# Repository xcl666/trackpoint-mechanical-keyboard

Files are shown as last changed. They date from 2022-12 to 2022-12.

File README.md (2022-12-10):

1，qmk源码里面，keyboard里面xcl文件夹，对应相应的键盘

2，PCB源码，嘉立创

3，固件，在qmk_firmware下有相应的固件名称

4，欢迎进QQ群199606725交流学习

5, 发现这样写太累了，抽个时间，写个word，好好梳理一下吧，再传上来。

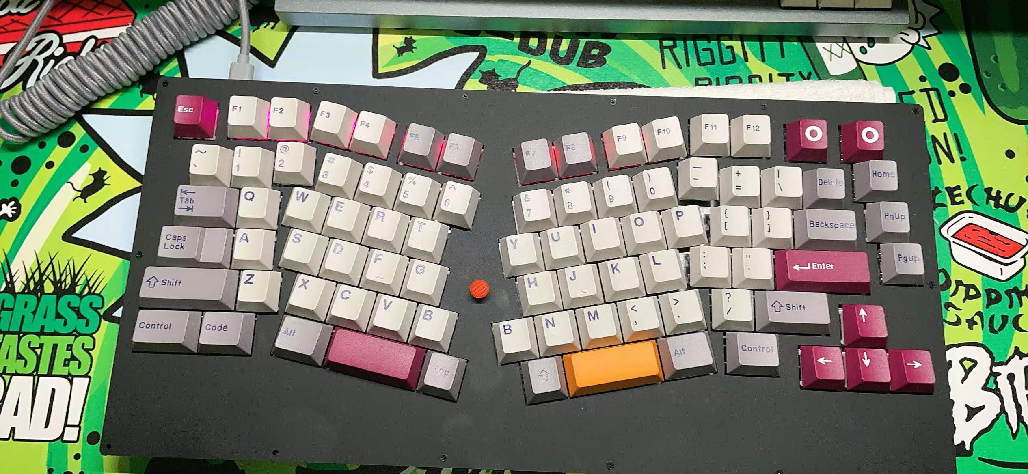
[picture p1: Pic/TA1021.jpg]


备注：qmk代码是参考 myst729

现在就开始讲一下怎么制作键盘了。

1， 先去嘉立创导入iceda里面的工程文件，打板子

2， 在嘉立创eda里面生产bom表，去淘宝或者嘉立创买各种元器件

3， 需要烙铁，风枪更好的，芯片多采用mu封装的，风枪还是必须的，如果手艺厉害，烙铁也可以，把各种元器件贴上去

4， 最好贴个最小系统，刷入qmk_firmware文件夹里面的hex估计，测试没问题，在焊二极管和轴座

5， 然后安装小红点模块，可以买8pin的0.5mm排线连接，顺序是V、G、C、L、M、R、R、D，中间三根不用焊，只要V G C R D这五根线

6， 需要用到PCB文件夹里面的外壳文件，亚克力切割外壳，定位板，定位板可以选择碳纤维、钢、亚克力等材质，规格是：

7， 外壳到了之后，需要2x12的铜柱，2x13的螺丝，2x6的螺丝

8，小红点支撑杆可以3D打印，有模型，不知道我传了没有。

9，装上轴和键帽，就走起了。

欢迎支持作者，让作者喝杯咖啡，继续完善DIY文档，哈哈，非常感谢

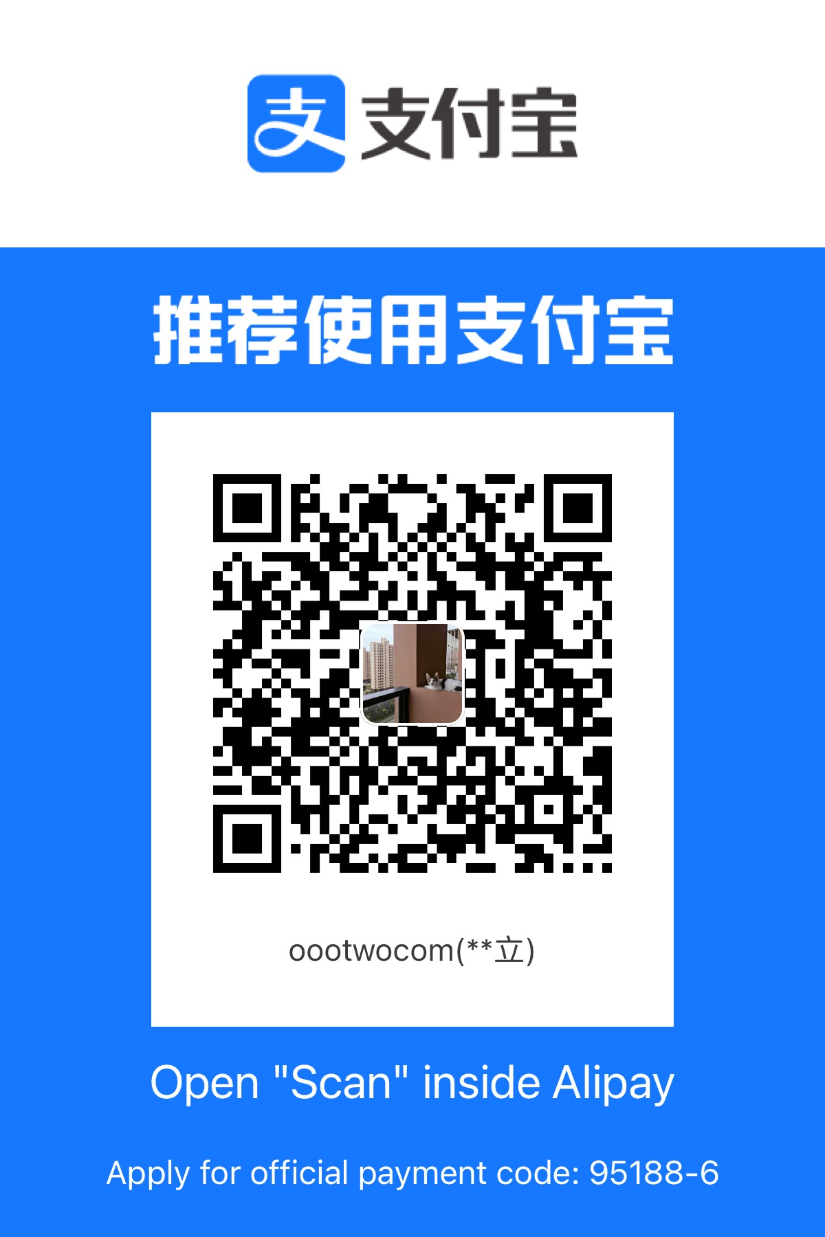
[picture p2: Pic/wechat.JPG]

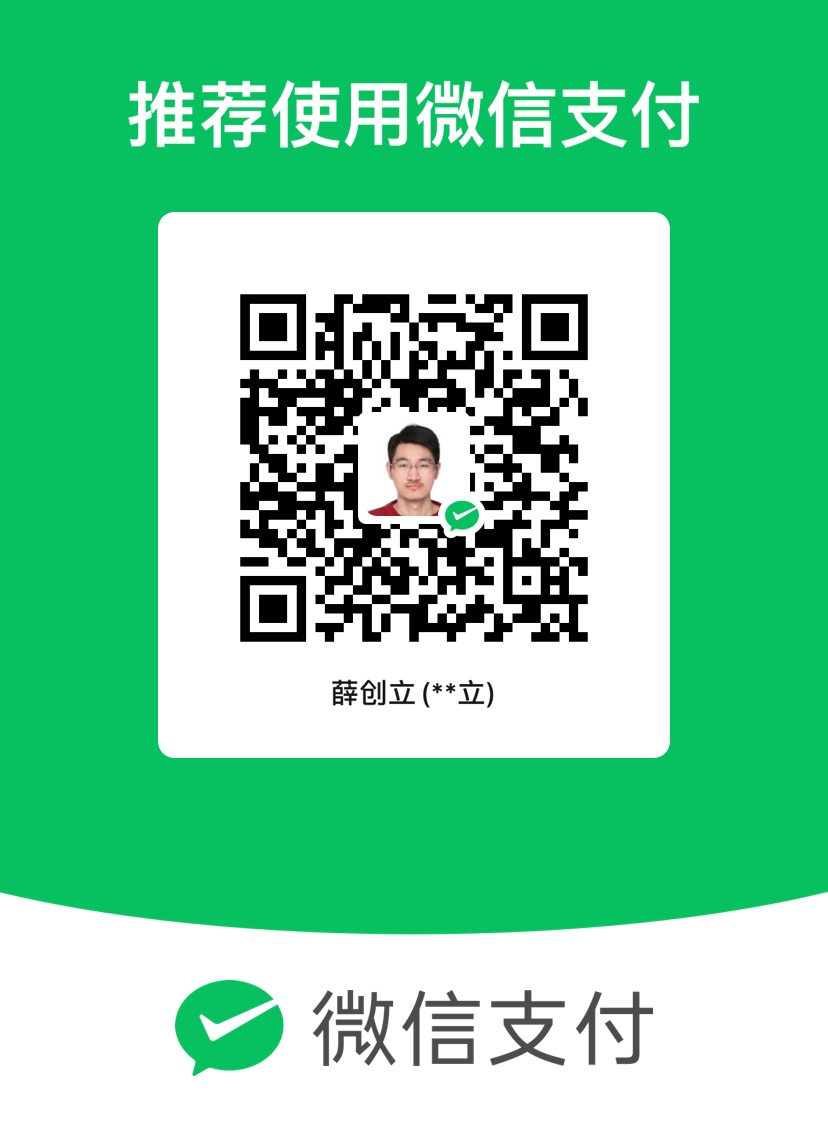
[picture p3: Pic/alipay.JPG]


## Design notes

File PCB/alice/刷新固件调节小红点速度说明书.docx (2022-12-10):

刷新固件调节小红点速度说明书

1. 在 群文件 qmk 里面下载安装qmk_toolbox.exe
2. 打开 qmk_toolbox.exe，勾选 autoflash，如下图

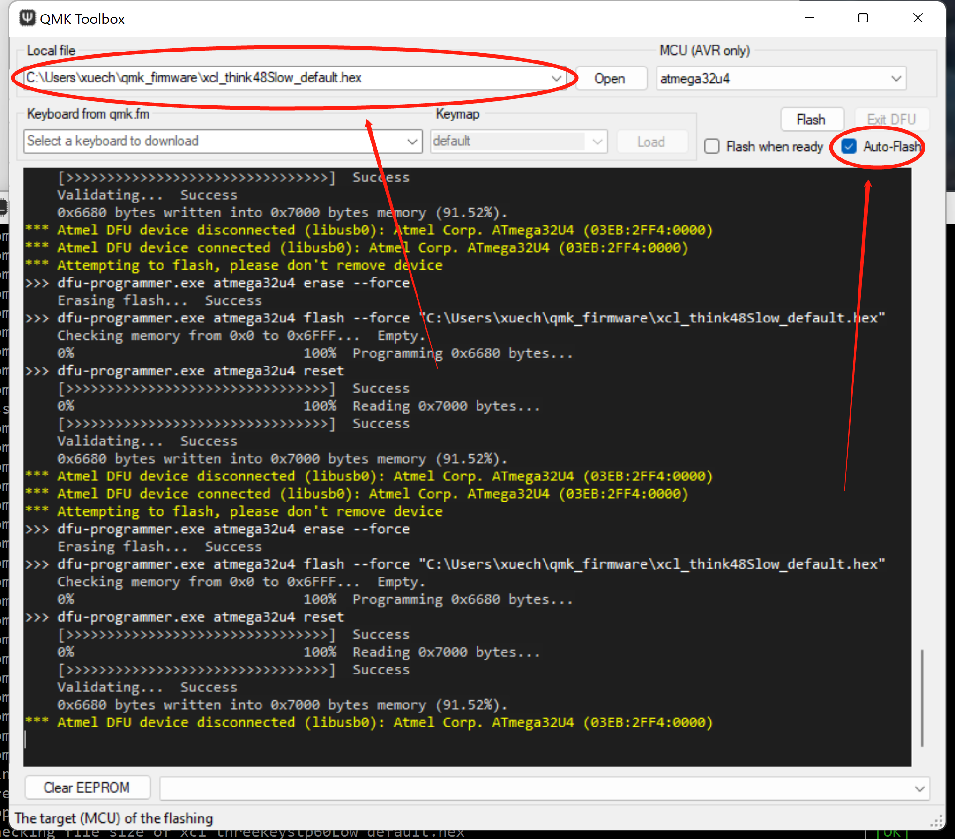
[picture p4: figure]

直接把 ***.hex 固件拖进图中方框里面

3，打开 via 软件

A. 按照下图箭头指向进行操作，保存当前键盘布局，以防出现刷固件之后出现按键回复刷机状态。

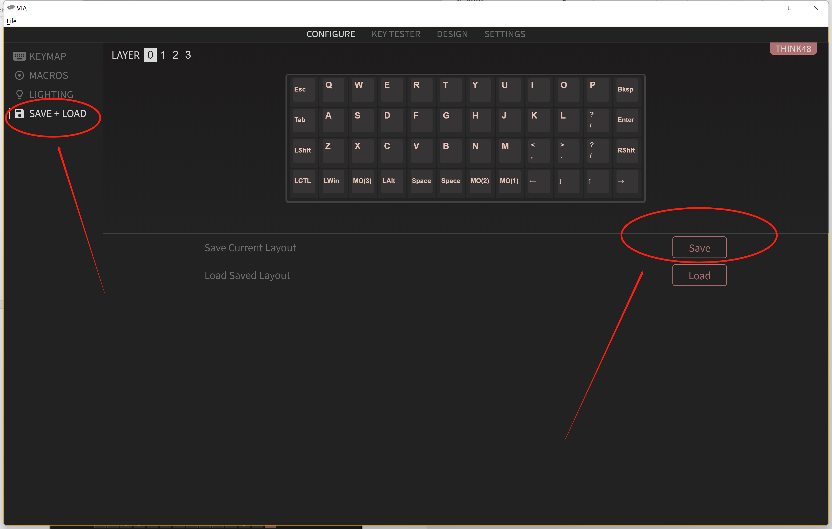
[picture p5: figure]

B. 按照下图操作，把 P 键设置为 Reset 按键

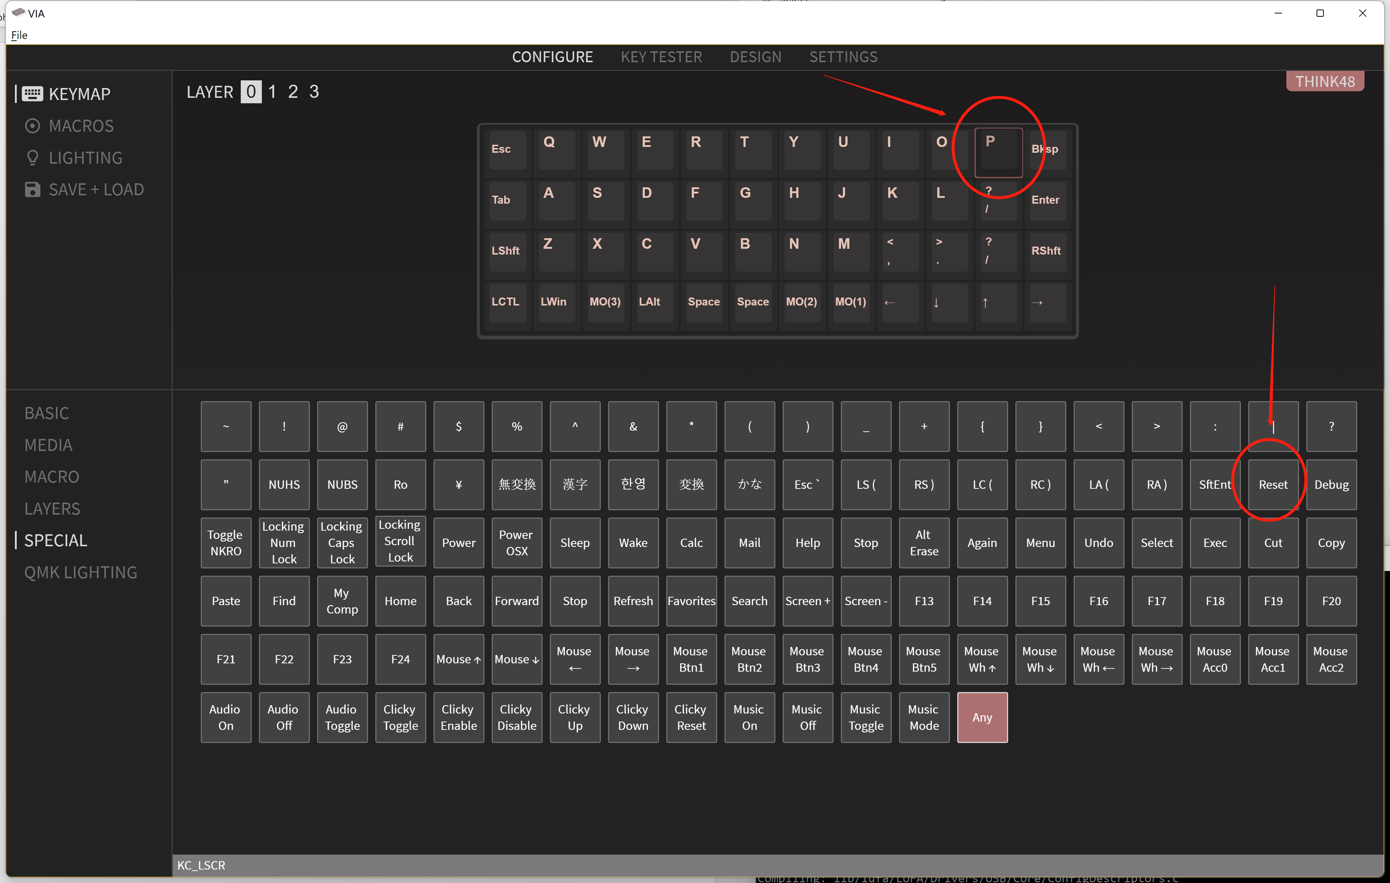
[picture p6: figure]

C. 然后点击 “ P ” 键，观察 qmktoolbox进行刷机进度，刷机完成之后，把键盘布局重新load 下来，如下图。

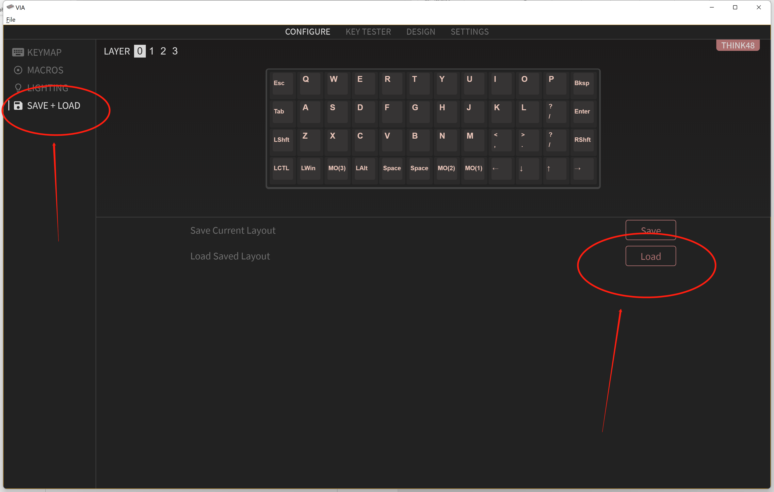
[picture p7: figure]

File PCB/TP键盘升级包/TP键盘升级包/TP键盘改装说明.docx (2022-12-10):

# 组装

###### 底座组装

组装前先插入键盘，测试下功能。小红点和所有按键都可以触发。

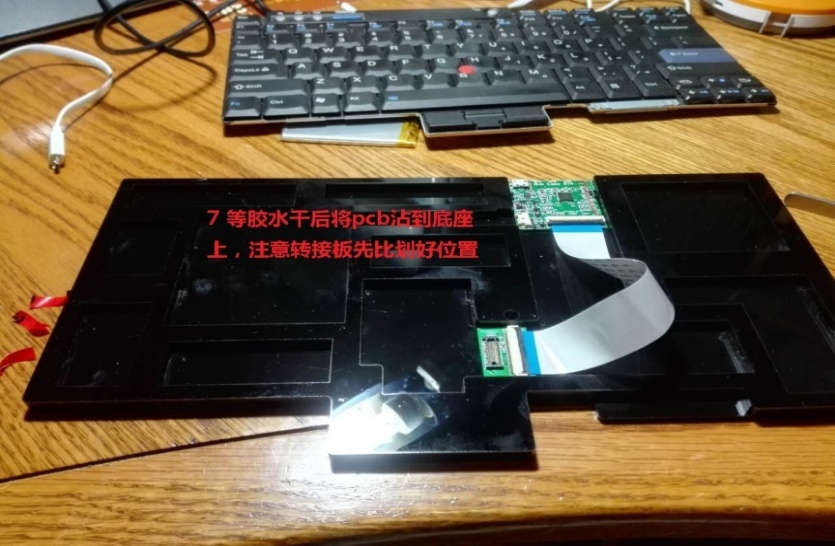
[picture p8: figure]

根据不同键盘找到转接板位置。固定白色排线。

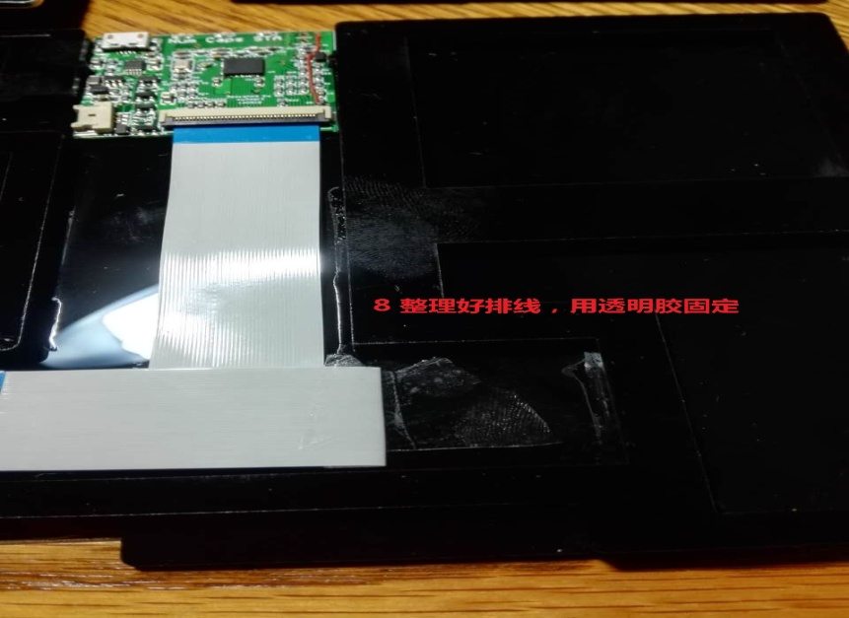
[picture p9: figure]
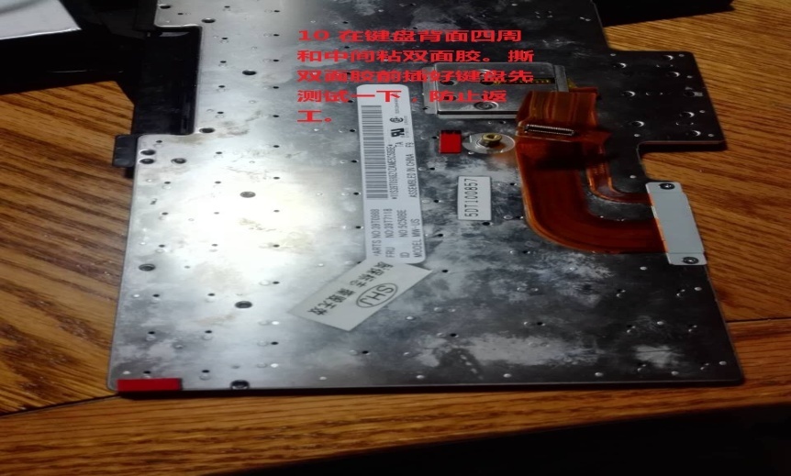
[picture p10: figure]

键盘背面粘双面胶。

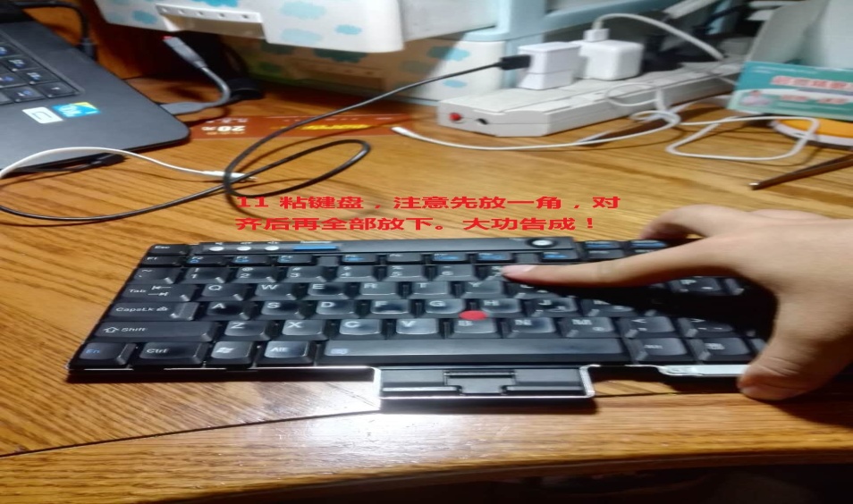
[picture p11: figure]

把键盘粘到底座上。

###### 单独PCB组装

# 简单使用

详细使用说明在升级包应用程序中的HELP按钮。

###### LED显示

未连接主机时：

num闪为蓝牙模式，cap亮未配对，灭已配对

cap 闪为 USB模式，num亮未配对，灭已配对

闪烁次数代表选择的信道号。

连接主机后：

num和cap用于正常键盘功能。

sta闪两下是正常，闪一下是小红点关闭，一直闪是电量低，常亮是正在充电。

###### 改变信道

同时按下(Fn + LCTRL + 数字)，1到4为蓝牙，5到8为usb接收器。

###### 删除配对

切换到需要删除配对的信道，然后同时按下(Fn + LCTRL + s)。

###### 重新配对

配对前先要根据LED状态确认该信道是未配对状态。接收器信道未配对状态下插入接收器即可配对。蓝牙模式用主机搜索，然后根据主机提示操作。

# 修改配置

在usb接收器模式下，打开升级包中的exe文件，先读取配置，然后根据需要修改，再下载配置。

# 高级使用

###### 修改键值表

1. 读取要修改按键的扫描码

采用USB接收器模式，点击“读扫描码”按钮，按下要修改的按键。显示的前4字节为当前扫描码，共能显示4个按键。其中fd为没有按键，fe为Fn按键。例如A键按下时显示扫描码为3a。

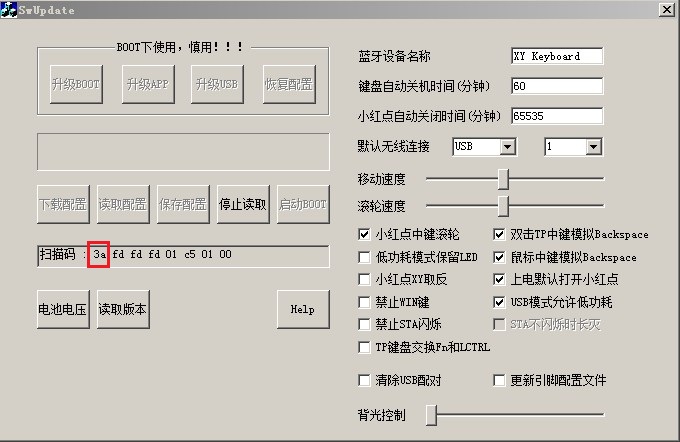
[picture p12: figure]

2. 修改键值表

用上面读取的扫描码找到该按键在键值表中的位置，并修改。例如A键的扫描码为3a，则A键在键值表中的位置为第3行，第a列，键值为0x0004。键值分三种类型：普通按键，控制按键和多媒体按键。键值从配置文件最后的三个附表中查找。更全面的键值的定义参见百度网盘中的Hut1_12v2.pdf文件第53（普通）和75（多媒体）页。键值为Usage ID列根据按键类型加前缀，普通按键加0x00，多媒体按键加0x8。

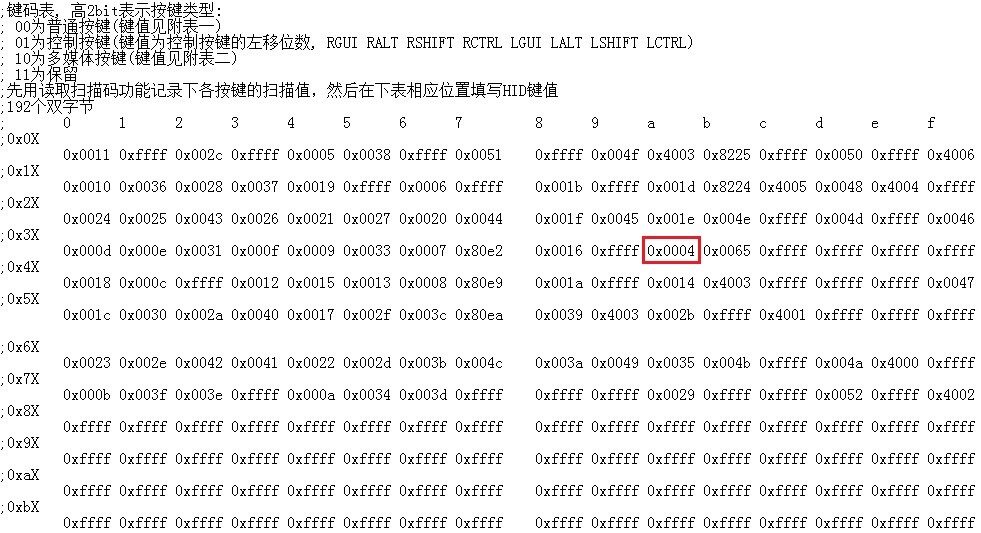
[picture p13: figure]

3. 下载配置文件：

修改完所有按键后关闭并保存配置文件。点击“停止读取”按钮，勾选“更新引脚配置文件”选项，点击“下载配置”按钮。下载配置后键盘自动关机，重新开机后即采用新的配置。

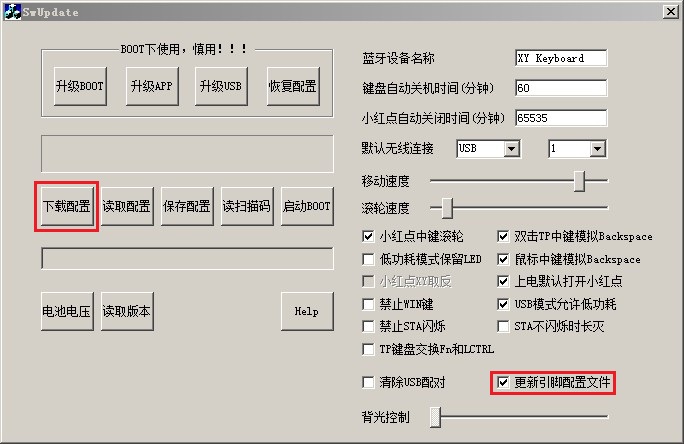
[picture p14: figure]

###### Fn和小键盘映射

映射表第一行为扫描码，第二行为映射键值。例如下箭头的扫描码为07，则第一行扫描码写0x07，第二行对应位置键值填写0x80cd(Play/Pause)。

ThinkPad的小键盘功能可以理解为带锁定的Fn映射，映射表可以更改为其它的功能。如果不使用小键盘，可以将“0x4f 0xfe”改为“0xff 0xff”，此时小键盘映射表变为上面Fn映射表的补充，共可实现36个Fn映射。

###### 可编程按键

可编程按键为当按下某个按键或按键组合，会自动发送一串预先定义的按键。出厂定义按下蓝键为发送“win+r www.51nb.com enter”实现访问51nb网站。

可定义5个可编程按键，每个定义包含4字节。前两字节为按键扫描码，例如第一行0x77为蓝键0xfd为无按键，第二行为Fn+A，第三行为LCTRL+A（组合按键的扫描码也是用读取扫描码功能读取的）。第三字节为发送内容的起始位置（可编程按键内容的第几行）。第四字节为长度，即从第三字节定义的位置开始发送多少行。

可编程按键内容表每行有9个字节：

第1字节为控制按键，每个bit分别代表“RGUI RALT RSHIFT RCTRL LGUI LALT LSHIFT LCTRL是否按下”。

第2字节固定为0x00。

第3-8字节普通按键键值(可从附表1中查找，去掉中间的00)，例如w的键值为0x1a。

第9字节为发送此行后的延时，单位为10毫秒。最后一组延时为0代表不发送所有按键抬起。

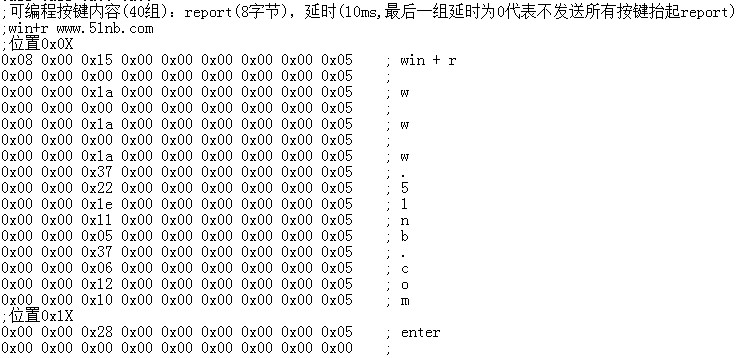
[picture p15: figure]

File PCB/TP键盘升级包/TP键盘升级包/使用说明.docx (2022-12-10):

# 简单使用

1 快速选择信道：同时按下(Fn + LCTRL + 数字)

1到4为蓝牙，5到8为usb接收器

2 清除当前信道配对：同时按下(Fn + LCTRL + s)

清除当前模式配对：同时按下(Fn + LCTRL + a)

清除当前模式是指蓝牙或接收器模式下的4个信道。

3 重新配对：

切换并清除要配对的信道。清除后，蓝牙模式cap常亮，

接收器模式num常亮，表示清除成功。

蓝牙模式 ：用主机搜索键盘，按提示操作

USB接收器：未配对信道下插入USB接收器

4 设置开机默认无线模式和信道：出厂默认USB接收器信道1

按6下ins -> F3 -> 数字(1到4为蓝牙，5到8为usb接收器)

高级使用：

本改装套件支持通过引脚配置文件修改键位，增加功能，编

辑可编程按键等高级功能。具体修改参看引脚配置文件内说明，

或旺旺咨询。

店铺地址：shop65864038.taobao.com

旺旺群 ：449483159

# 更新日志

2018.05.17

1 修改了TP二代主板等待Fn抬起的bug

2 更新了使用说明

2018.05.14

1 修改了带USB主板鼠标中键不起作用的bug

2 增加关机键在引脚配置文件中可配置功能

2018.01.10

1 增加层切换功能，支持8个层，可锁定和非锁定

2 增加Pn映射，映射表在键值表0x80以上位置

3 增强键值表，可定义组合按键，发送可编程按键和模拟鼠标

4 关闭小红点按键可自定义

5 修改sta灯常灭模式关闭小红点后闪烁的bug

6 修改蓝牙配对码为5位数时可能死机的bug

2017.10.21

1 解除Fn只能同时按下一个按键的限制

2 增加Fn和lctrl互换功能

2017.08.01

1 增加正常工作模式下STA禁止闪烁功能

2 增加读取电池电压功能

3 增加读取版本号(编译日期)功能

2017.02.28

1 增加USB模式下是否进入低功耗模式选项

2 修改快速切换主机时没有发送全部按键抬起的bug

3 增加Fn功能最多按键数

2016.11.25

1 改进了LED信息显示方式，可以显示配对状态

2 增加(Fn + LCTRL + 数字)快速选择信道等快捷键

3 无USB的主板关闭小红点后进入低功耗状态，更加省电

4 增加可编程按键等功能，在引脚配置文件中修改

5 修改PC软件配置界面，增加帮助等

2016.01.05

1 修改了win8等某些主机无法蓝牙配对的bug。

2 升级软件需要先读取配置才能下载配置。

2015.12.25

1 增加小红点灵敏度调节。

2 增加带USB主板的USB控制器升级。

3 增加PC配置界面。

4 增加引脚配置文件，可以自定义按键扫描码等。

2015.10.13

更新了中键滚轮调速方式，防止报告速率过快。

# 开关机和充电

开关机：

开机：按住电源键，等三个LED全部亮起后松开。

关机：开机状态下按电源键则关机。

若开机后三个LED闪烁若干次后关机，则表示电池电量低。

二代主板无硬件关机功能。插入电池后在BOOT中等待约10秒

后进入工作状态，自动或指定键进入休眠。

自动关机和自动关闭小红点：

可配置无操作一定时间后自动关闭键盘或小红点。

在丢失无线连接5秒后自动关闭键盘。

关闭小红点：

此功能只适用于不带usb的版本。

小红点打开时按Fn+F8关闭小红点。

小红点关闭后按Fn+F8打开小红点。

小红点开机默认状态可配置。

充电：

电池容量为2000mah，预计充电时间为8小时左右。

充电时打开键盘，STA灯表示充电状态，常亮为正在充电，

不亮或闪烁为已充满。键盘关闭时无法显示充电状态。

# LED指示灯

按优先级显示，有高优先级要显示的则会忽略低优先级的。

NUM 和 CAPS 灯：

模式 优先级 状态说明

配置 1 num闪等待选择功能，cap闪等待选择参数

无连接 2 num闪为蓝牙模式，cap亮未配对，灭已配对

cap闪为 USB模式，num亮未配对，灭已配对

闪烁次数代表选择的信道

正常 3 num和cap用于正常键盘功能

BOOT num和cap交替闪烁表示等待插入接收器

STA 灯：

模式 优先级 状态说明

充电 1 常亮，需开机否则不亮

电量低 2 快闪

正常 3 闪2下小红点打开，闪1下小红点关闭

# 无线连接

支持两种无线模式：USB接收器和蓝牙4.0BLE。

每种无线模式有4个信道，每个信道只能配对一个主机接收器。

快速选择无线模式和信道：

方法一：连续按3下pause键(引脚配置文件中可修改)，cap闪

烁，再按数字键选择主机。

方法二：(Fn + LCTRL + 数字) 同时按下

数字1到4为蓝牙，5到8为USB接收器。

此功能不改变上电默认无线模式和信道。

USB接收器配对：

未配对状态下(cap闪num常亮)，插入USB接收器，键盘自动

关机。重新打开键盘，配对成功。此模式配对会改变默认无线

模式和信道。

蓝牙4.0BLE配对：

未配对状态下(num闪cap常亮)，用主机搜索键盘，按主机提

示操作。此模式配对不会自动关机，也不会改变默认无线模式

和信道。重新配对时，请先删除主机端的原配对信息。

清除配对信息：

方法一：按6下ins键(引脚配置文件中可修改)，进入配置模式

选择清除模式 a键 当前无线模式下全部信道

s键 当前无线模式下当前信道

数字1键，开始清除。

方法二：(Fn + LCTRL + a)，清除当前无线模式下全部信道。

(Fn + LCTRL + s)，清除当前无线模式下当前信道。

# 修改配置

两种配置模式：PC配置软件(需通过USB接收器)和快捷键。

PC配置软件：

1 打开键盘，用USB接收器模式与电脑连接。

2 打开PC配置软件，点击“读取配置”。

3 修改配置。APP升级后需要选择“更新引脚配置文件”。

4 点击“下载配置”。

快捷键配置：

1 连续按6下ins键(引脚配置文件中可修改)，进入配置模式。

2 num快闪，按Fx或字母选择配置内容。

3 cap快闪，按数字键选择配置参数。

4 等待3秒钟后键盘自动关机，再开机使用新配置。

功能和参数选择表：

功能 参数

r 重置全部配置 数字1重置全部配置。包括USB接收器配对

信息，但不包括蓝牙配对信息。

a 清除全部配对 数字1清除当前无线模式下所有信道配对

s 清除当前配对 数字1清除当前无线模式下当前信道配对

F1 自动关机时间 数字0到9分别为无限，15分钟, 30分钟,

F2 TP自动关闭时间 45分钟, 1小时，2小时，3小时，4小时，

5小时，6小时。

F3 默认连接主机 数字1到4为蓝牙，5到8为usb接收器。

F4 中键滚轮速度 数字1到9为从慢到快。0为关闭滚轮，

用作鼠标中键。

F5 鼠标中键 数字0鼠标中键作为backspace键

数字1作为鼠标中键

F6 小红点灵敏度 数字1到9为从慢到快

# 固件升级

主板支持通过USB接收器升级固件。升级顺序：

升级BOOT（如果需要）->升级APP ->重新配对和下载配置

升级固件需要在BOOT中进行，进入BOOT的方法：

1 用接收器方式可正常使用键盘，点击“启动BOOT”按钮。

2 无法使用方法1时可用下面方法强行进入BOOT。

一代主板按住蓝键开机，num和cap交替闪，表示进入BOOT。

二代主板插入电池后，直接进入BOOT。

num和cap交替闪烁时插入接收器，停止闪烁表示已配对。

注意：主板只在BOOT中停留约10秒，插入接收器要快。

进入BOOT且配对后即可进行下面操作。

BOOT升级：

1 点击“升级BOOT”按钮，等待升级结束。若长时间进度条停

止，则可能是通信受到干扰。重新进入BOOT再试。

2 一代主板需按电源按钮打开键盘。

num亮5秒后进入BOOT(num和cap交替闪)，升级成功。拔插下

接收器，重新配对，然后升级APP。

BOOT升级后每次上电都会进入BOOT，等待升级APP。

"

APP升级：

1 点击“升级APP”按钮，等待升级结束。若长时间进度条停

止，则可能是通信受到干扰重新进入BOOT再试。

2 一代主板需按电源按钮打开键盘。

升级后num常亮，cap闪一下，表示进入接收器信道1，拔插

下接收器重新配对。

3 点击“读取配置”按钮，勾选“更新引脚配置文件”选项，

根据需要修改其它选项。

4 点击“下载配置”按钮。除特定型号外，其他键盘选T60。

BOOT下恢复配置：清除所有配对信息和用户设置。

1 进入BOOT且配对，点击“恢复配置”按钮。

2 恢复后需要重新配对和下载引脚配置。

提示：升级时尽量将键盘靠近USB接收器，提高通信质量 。

升级是通过BOOT进行的，老BOOT升级时LED指示和现版本

不一样，但过程一样。参看老版本说明文件。

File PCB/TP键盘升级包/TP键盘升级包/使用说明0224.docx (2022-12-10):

# 简单使用

1 快速选择信道：同时按下(Fn + LCTRL + 数字)

1到4为蓝牙 9为有线模式

2 清除当前信道配对：同时按下(Fn + LCTRL + s)

清除当前模式配对：同时按下(Fn + LCTRL + a)

清除当前模式是指蓝牙模式下的4个信道。

3 设置开机默认无线模式和信道：出厂默认USB接收器信道1

按6下ins -> F3 -> 数字(1到4为蓝牙)

# 开关机

开关机：

开机：按住电源键

关机：开机状态下按电源键则关机。

充电：

电池容量为5000mah，预计充电时间为20小时左右。

# 修改配置

快捷键配置：

1 连续按6下ins键，进入配置模式。

2 按Fx或字母选择配置内容。

3 按数字键选择配置参数。

。

功能和参数选择表：

功能 参数

a 清除全部配对 数字1清除当前无线模式下所有信道配对

s 清除当前配对 数字1清除当前无线模式下当前信道配对

F1 自动关机时间 数字0到9分别为无限，15分钟, 30分钟,

F2 TP自动关闭时间 45分钟, 1小时，2小时，3小时，4小时，

5小时，6小时。

F3 默认连接主机 数字1到4为蓝牙

F4 中键滚轮速度 数字1到9为从慢到快。0为关闭滚轮，

用作鼠标中键。

F5 鼠标中键 数字0鼠标中键作为backspace键

数字1作为鼠标中键

F6 小红点灵敏度 数字1到9为从慢到快

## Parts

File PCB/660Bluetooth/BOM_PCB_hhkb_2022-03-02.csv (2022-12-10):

ID | Name | Designator | Footprint | Quantity | Manufacturer Part | Manufacturer | Supplier | Supplier Part | Price
1 | 凯华_无灯_二极管V1 | KH8,KH9,KH10,KH11,KH12,KH13,KH14,KH15,KH16,KH17,KH18,KH19,KH20,KH21,KH22,KH23,KH24,KH25,KH26,KH27,KH28,KH29,KH30,KH31,KH32,KH33,KH34,KH35,KH36,KH37,KH38,KH39,KH40,KH41,KH42,KH43,KH44,KH45,KH46,KH47,KH48,KH49,KH50,KH51,KH52,KH53,KH54,KH55,KH56,KH57,KH58,KH59,KH60,KH61,KH62,KH63,KH64,KH65,KH66,KH67,KH68,KH69,KH1,KH2,KH3,KH4,KH5,KH6,KH7 | 凯华_无灯_二极管V1 | 69
2 | 3x6x2.5 | RESET1 | KEY-3.0*6.0 | 1 | 3x6x2.5Red head high temperature | ReliaPro | LCSC | C46491 | 0.1425
3 | 22 | 22,2201 | R0603 | 2 | 0603WAF220JT5E | UniOhm | LCSC | C23345 | 0.0079
4 | 5.1K | 5.1K,5.1K1 | R0805 | 2 | 0805W8F5101T5E | UniOhm | LCSC | C27834 | 0.0164
5 | MF-NSMF050-2 | 500MA | F1206 | 1 | MF-NSMF050-2 | BOURNS | LCSC | C75464 | 0.1632
6 | KH-FG1.0-H2.0-8PIN | CN2 | FPC-SMD_KH-FG1.0-H2.0-8PIN | 1 | KH-FG1.0-H2.0-8PIN | kinghelm(金航标) | LCSC | C2797225 | 0.6263
7 | 4pin焊盘 | P1 | 4PIN焊盘 | 1 | XHB-4A(White)/4needle | BOOMELE | LCSC | C61277 | 0.1133
8 | PRTR5V0U2X | SOT1 | SOT-143_L2.9-W1.3-P1.92-LS2.3-BL | 1 | PRTR5V0U2X | Yenji Elec | LCSC | C330092 | 0.5249
9 | TYPE-C-31-M-12 | USBC1 | USB-C_SMD-TYPE-C-31-M-12 | 1 | TYPE-C-31-M-12 | Rectangular Connectors - Contacts | LCSC | C165948 | 2.05
10 | KH-CL0.5-H2.0-40PIN | CN1 | FPC-SMD_KH-CL0.5-H2.0-40PIN | 1 | KH-CL0.5-H2.0-40PIN | kinghelm(金航标) | LCSC | C2797203 | 0.8974

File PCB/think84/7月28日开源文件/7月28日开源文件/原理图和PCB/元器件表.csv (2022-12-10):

ID | Name | Designator | Footprint | Quantity | Manufacturer Part | Manufacturer | Supplier | Supplier Part | Price | Paste Type | Assembly Type | JLCPCB Part Class
1 | 22pF | C1,C2 | C0805 | 2 | 0805CG220J500NT | FH | LCSC | C38143 | 0.0986
2 | 100nF | C3,C4,C5,C6 | C0805 | 4 | 0805B104J500NT | FH | LCSC | C29926 | 0.0662
3 | 470nF | C7 | C0805 | 1 | 0805B474K500NT | FH | LCSC | C49955 | 0.1041
4 | 1uF | C8 | C0805 | 1 | CL21B105KBFNNNE | SAMSUNG | LCSC | C28323 | 0.0645 | base | smtWeld
5 | MM1Z5V6 | D1,D2,D3,D4,D5,D6,D7,D8,D9,D10,D11,D12,D13,D14,D15,D16,D17,D18,D19,D20,D21,D22,D23,D24,D25,D26,D27,D28,D29,D30,D31,D32,D33,D34,D35,D36,D37,D38,D39,D40 | SOD-123_L2.8-W1.8-LS3.7-RD | 40 | MM1Z5V6 | SEMTECH | LCSC | C85210 | 0.1075 |  |  | Extended Part
6 | Switch3x4x2 | KEY1 | KEY-3.0*4.0 | 1 | Switch3x4x2 | ReliaPro | LCSC | C26638 | 0.2349
7 | 10K | R1,R2 | R0805 | 2 | RC0805FR-0710KL | YAGEO | LCSC | C84376 | 0.0206
8 | 22 | R3,R4 | R0805 | 2 | RC0805FR-0722RL | YAGEO | LCSC | C107702 | 0.0229
9 | ATMEGA32U4-AU | U1 | QFP-44_L10.0-W10.0-P0.80-LS13.2-BL | 1 | ATMEGA32U4-AU | MICROCHIP | LCSC | C44854 | 34.71 | expand | smtWeld
10 | MX1u | U4,U5,U6,U7,U8,U9,U10,U11,U12,U13,U14,U15,U16,U17,U18,U19,U20,U21,U22,U23,U24,U25,U26,U27,U28,U29,U30,U31,U32,U33,U34,U35,U36,U37,U38,U39,U40,U41,U42,U43 | MX1U | 40
11 | TYPE-C-31-M-12 | USBC1 | TYPE-C-USB-17 | 1 | TYPE-C-31-M-12 | Rectangular Connectors - Contacts | LCSC | C165948 | 1.77
12 | 16MHz | X1 | OSC-SMD_2P-L5.0-W3.2 | 1 | XSHEELNANF-16MHZ | TAITIEN Elec | LCSC | C242221 | 1.6022

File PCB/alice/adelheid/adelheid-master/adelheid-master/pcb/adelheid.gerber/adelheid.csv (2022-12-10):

Comment | Designator | Footprint | LCSC
22pF | C1,C2 | Capacitors_SMD:C_0805_HandSoldering | C1804
10uF | C3 | Capacitors_SMD:C_0805_HandSoldering | C15850
1uF (±10%) | C4 | Capacitors_SMD:C_0805_HandSoldering | C28323
1uF | C5 | Capacitors_SMD:C_0805_HandSoldering | C28323
0.1uF | C6,C8,C7,C9 | Capacitors_SMD:C_0805_HandSoldering | C49678
D | D1,D7,D29,D35,D23,D12,D18,D57,D51,D46,D40,D62,D72,D67,D77,D78,D68,D73,D63,D8,D41,D47,D52,D58,D19,D13,D2,D24,D36,D30,D79,D69,D74,D64,D9,D42,D48,D53,D59,D20,D14,D3,D25,D37,D31,D80,D70,D65,D10,D43,D49,D54,D60,D21,D15,D26,D38,D32,D81,D75,D66,D11,D44,D50,D55,D61,D22,D16,D27,D39,D33,D82,D71,D76,D45,D56,D17,D6,D28,D34,D4,D5 | Diode_SMD:D_SOD-123 | C241939
LED | LS8,LS7,LS6,LS5,LS4,LS2,LS16,LS15,LS1,LS17,LS14,LS11,LS10,LS3,LS9,LS13,LS12 | LED_SMD:LED_0805_2012Metric_Pad1.15x1.40mm_HandSolder | C34499
2N7002 | Q1 | Package_TO_SOT_SMD:SOT-23 | C8545
22 | R1,R2 | Resistor_SMD:R_0805_2012Metric_Pad1.15x1.40mm_HandSolder | C17561
10K | R3,R4 | Resistor_SMD:R_0805_2012Metric_Pad1.15x1.40mm_HandSolder | C17414
1.5K | R5 | Resistor_SMD:R_0805_2012Metric_Pad1.15x1.40mm_HandSolder | C4310
R | RL1,RL46,RL12,RL29,RL23,RL7,RL18,RL62,RL57,RL35,RL51,RL40,RL67,RL77,RL72,RL68,RL73,RL78,RL41,RL52,RL36,RL58,RL63,RL2,RL19,RL8,RL24,RL30,RL13,RL47,RL69,RL74,RL79,RL42,RL53,RL37,RL59,RL64,RL3,RL20,RL9,RL25,RL31,RL14,RL48,RL70,RL80,RL43,RL54,RL38,RL60,RL65,RL21,RL10,RL26,RL32,RL15,RL49,RL75,RL81,RL44,RL55,RL39,RL61,RL66,RL22,RL11,RL27,RL33,RL16,RL50,RL71,RL76,RL82,RL45,RL56,RL6,RL34,RL17,RL28,RL4,RL5,RS8,RS7,RS6,RS5,RS4,RS2,RS1,RS17,RS15,RS16,RS14,RS12,RS11,RS10,RS3,RS9,RS13 | Resistor_SMD:R_0805_2012Metric_Pad1.15x1.40mm_HandSolder | C17798
USBLC6-2SC6 | U1 | TO_SOT_Packages_SMD:SOT-23-6_Handsoldering | C7519
ATmega32U4-AU | U2 | Housings_QFP:TQFP-44_10x10mm_Pitch0.8mm | C44854
Crystal_GND24 | Y1 | Crystals:Crystal_SMD_SeikoEpson_FA238-4pin_3.2x2.5mm_HandSoldering | C13738

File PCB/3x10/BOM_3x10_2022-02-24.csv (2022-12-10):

ID | Name | Designator | Footprint | Quantity | Manufacturer Part | Manufacturer | Supplier | Supplier Part | Price
1 | 1K | 1K | R0805 | 1 | TC0525F1001T5E | UniOhm | LCSC | C75781 | 0.0764
2 | 1uF | 1UF | C0805 | 1 | CL21B105KBFNNNE | SAMSUNG | LCSC | C28323 | 0.0554
3 | 5.1K | 5.1K,5.1K1 | R0805 | 2 | 0805W8F5101T5E | UniOhm | LCSC | C27834 | 0.0153
4 | 10K | 10K | R0805 | 1 | 0805W8F1002T5E | UniOhm | LCSC | C17414 | 0.0134
5 | 22 | 22,2201 | R0805 | 2 | 0603WAF220JT5E | UniOhm | LCSC | C23345 | 0.0079
6 | 22pF | 22PF,22PF01 | C0805 | 2 | CL21C220JBANNNC | SAMSUNG | LCSC | C1804 | 0.0708
7 | 100nF | 100NF01,100NF02,100NF03,100NF04 | C0805 | 4 | CL21B104KBCNNNC | SAMSUNG | LCSC | C1711 | 0.0309
8 | 470nF | 470NF | C0805 | 1 | CL21B474KBFNNNE | SAMSUNG | LCSC | C13967 | 0.0884
9 | MF-NSMF050-2 | 500MA | F1206 | 1 | MF-NSMF050-2 | BOURNS | LCSC | C75464 | 0.1548
10 | CD4148WSP | D1,D2,D3,D4,D5,D6,D7,D8,D9,D10,D11,D12,D13,D14,D15,D16,D17,D18,D19,D20,D21,D22,D23,D24,D25,D26,D27,D28,D29,D30 | D0805-RD | 30 | CD4148WSP | SUP | LCSC | C53365 | 0.0876
11 | ATMEGA32U4-MU | MCU | VQFN-44_L7.0-W7.0-P0.50-BL-EP5.2 | 1 | ATMEGA32U4-MU | MICROCHIP | LCSC | C112161 | 64.52
12 | 3x6x2.5 | RESET1 | KEY-3.0*6.0 | 1 | 3x6x2.5Red head high temperature | ReliaPro | LCSC | C46491 | 0.1425
13 | PRTR5V0U2X | SOT1 | SOT-143_L2.9-W1.3-P1.92-LS2.3-BL | 1 | PRTR5V0U2X | Yenji Elec | LCSC | C330092 | 0.5249
14 | TYPE-C-31-M-12 | USBC1 | USB-C_SMD-TYPE-C-31-M-12 | 1 | TYPE-C-31-M-12 | Rectangular Connectors - Contacts | LCSC | C165948 | 1.99
15 | 凯华轴座 | W1,W2,W3,W4,W5,W6,W7,W8,W9,W10,W11,W12,W13,W14,W15,W16,W17,W18,W19,W20,W21,W22,W23,W24,W25,W26,W27,W28,W29,W30 | 凯华轴座 | 30
16 | 16MHz | X2 | OSC-SMD_4P-L3.2-W2.5-BL | 1 | X322516MRB4SI | YXC | LCSC | C70562 | 0.5925

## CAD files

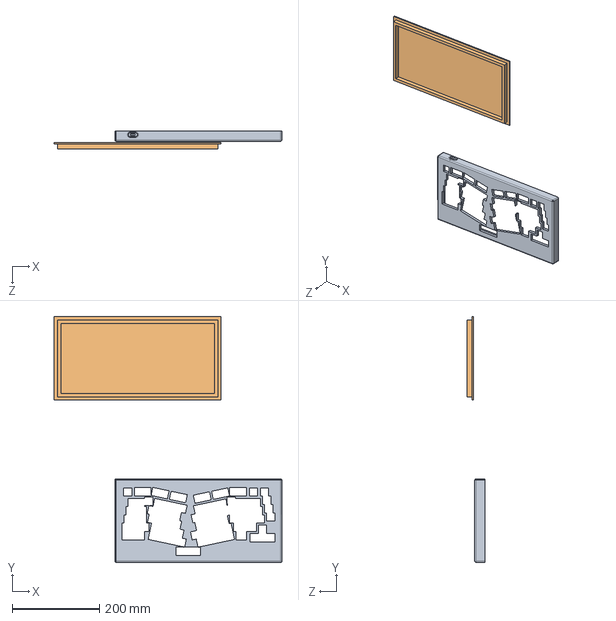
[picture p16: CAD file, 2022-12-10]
PCB/alice/3D/myown/装配体1.SLDASM
523.0 x 564.6 x 41.1 mm
上盖V2
零件3

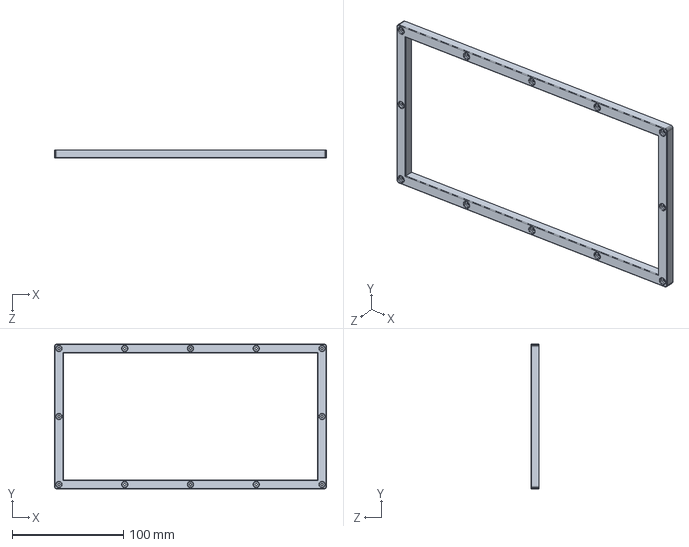
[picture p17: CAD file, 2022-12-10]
PCB/12x6/3D/top.SLDPRT
244.6 x 130.3 x 7.00 mm

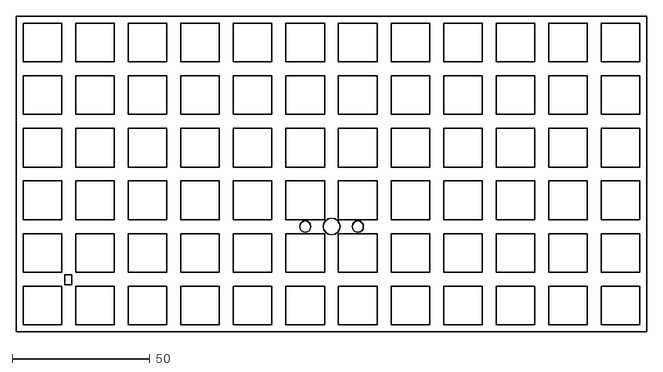
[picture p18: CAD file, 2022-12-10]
PCB/12x6/pcbV1.dxf
228.6 x 114.3

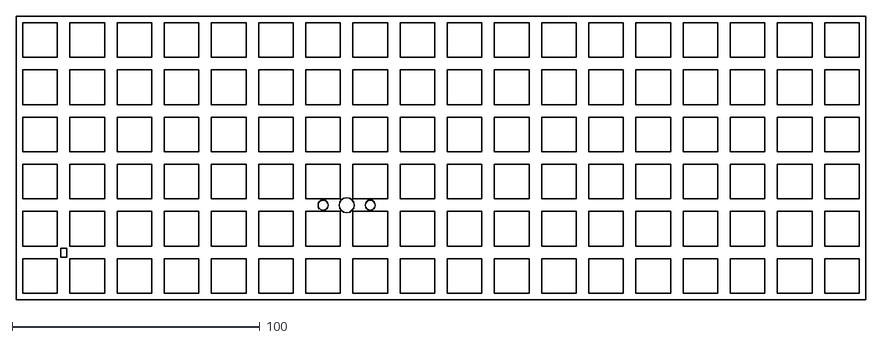
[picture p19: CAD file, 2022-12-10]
PCB/18x6/pcbv1.dxf
342.9 x 114.3

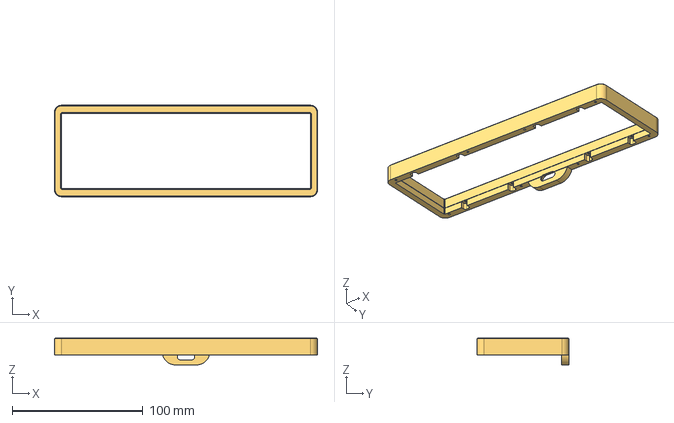
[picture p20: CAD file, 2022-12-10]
PCB/3x10/3D/30/上盖 (1).step
201.4 x 70.1 x 20.6 mm

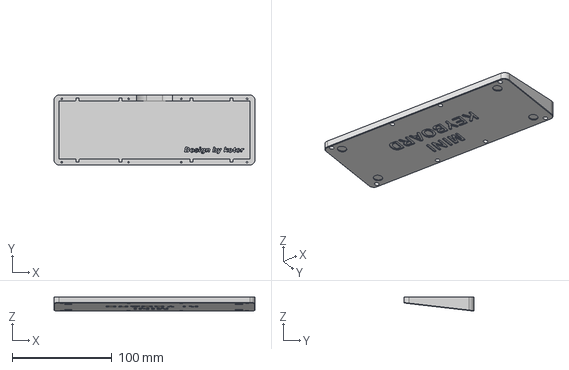
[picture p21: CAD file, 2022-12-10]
PCB/3x10/3D/stepp/底盖.step
201.4 x 70.1 x 14.2 mm

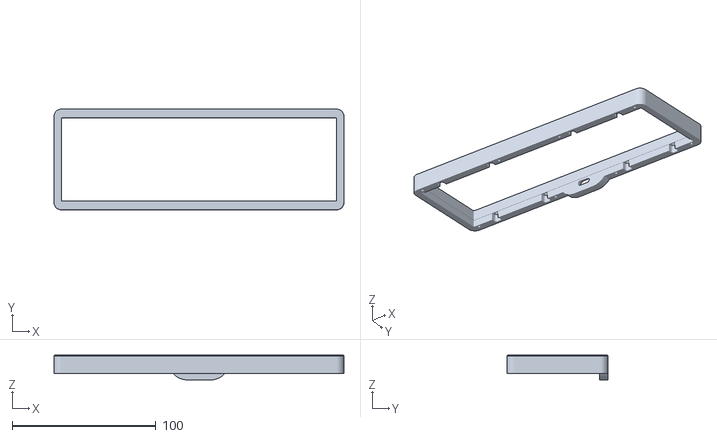
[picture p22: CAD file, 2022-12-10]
PCB/3x10/3D/上盖 (1).stl
201.4 x 70.1 x 17.3

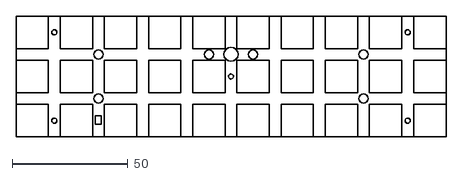
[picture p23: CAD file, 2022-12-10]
PCB/3x10/closepcbV1.dxf
185.4 x 52.1

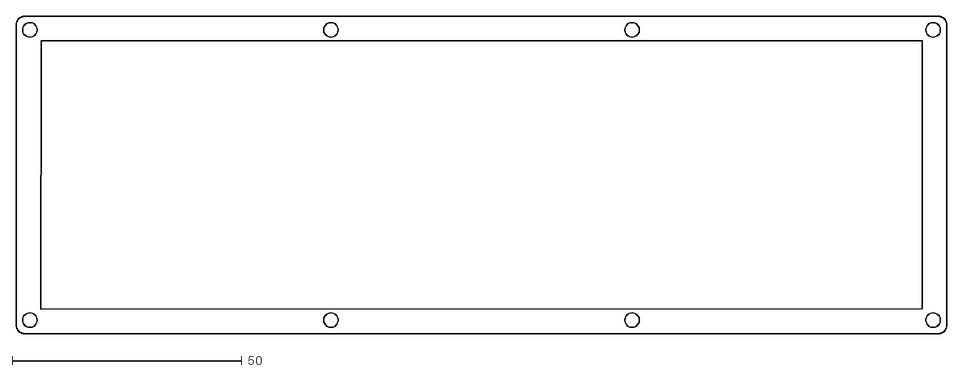
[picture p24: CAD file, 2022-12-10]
PCB/3x10/shell/2013/closedv1.dxf
202.5 x 69.2

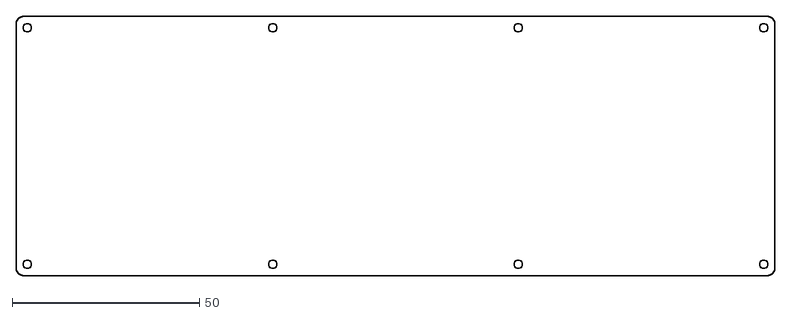
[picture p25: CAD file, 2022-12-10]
PCB/3x10/shell/bottom.dxf
202.5 x 69.2

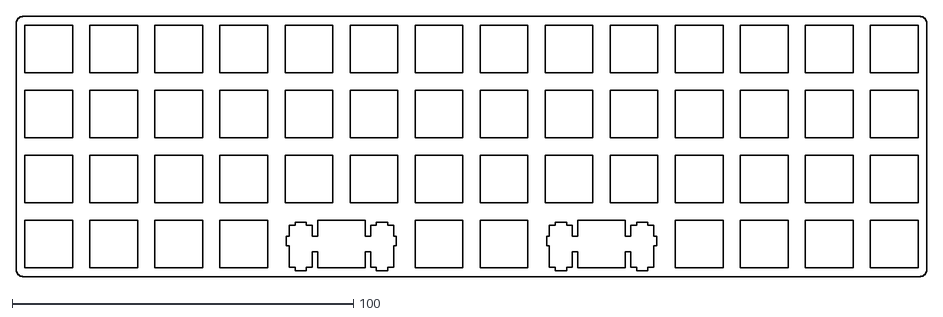
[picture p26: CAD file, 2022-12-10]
PCB/4x14/4x14pcb_Edge_2.dxf
266.7 x 76.2

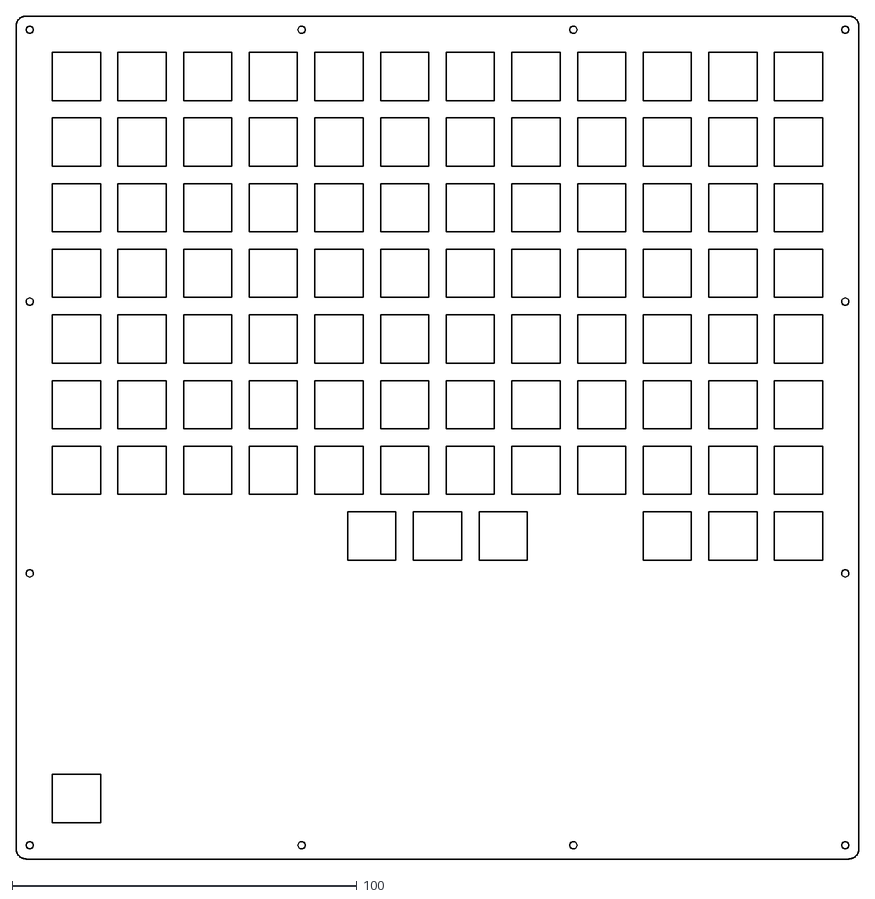
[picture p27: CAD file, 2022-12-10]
PCB/6x12Threekeys/945da17905b3b3941b72637ebe5409405d961628_switch.dxf
244.6 x 244.6

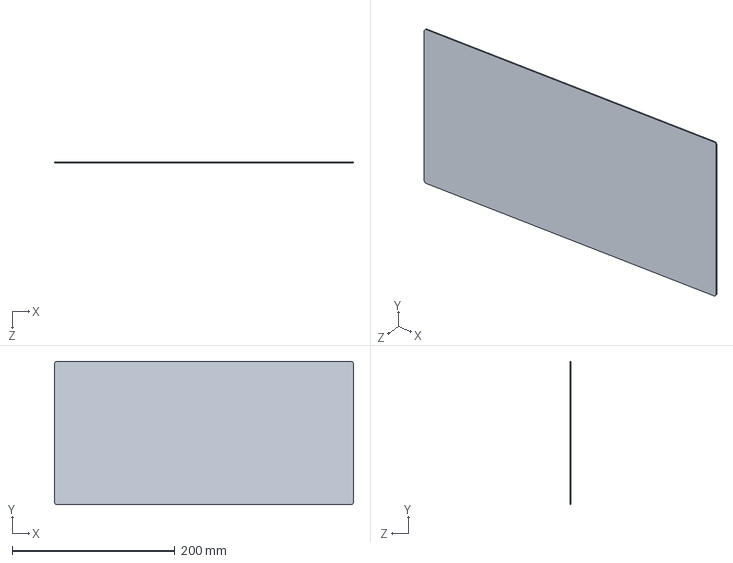
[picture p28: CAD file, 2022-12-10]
PCB/alice/3D/myown/new/底棉.SLDPRT
367.5 x 176.0 x 1.30 mm

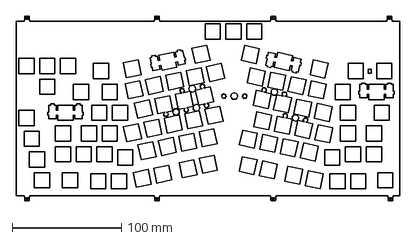
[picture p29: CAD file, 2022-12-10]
PCB/alice/3D/TA1021/TA1021定位板.dxf
351.5 x 169.0 mm

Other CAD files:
PCB/alice/3D/myown/new/组装.SLDASM
PCB/3x10/3D/加宽一点/30上盖 (1).step
PCB/alice/3D/TA上盖.step
PCB/alice/88c5caf0cc8206b7d507fcfc2c8e6fd27b87e487_switchv2.dxf
PCB/12x6/12x6pcbV1.dxf
PCB/12x6/3D/top.STL
PCB/12x6/pcb.dxf
PCB/12x6/shell/6x12switchV1.dxf
PCB/12x6/shell/bottom.dxf
PCB/12x6/shell/closed.dxf
PCB/12x6/shell/closedv1.dxf
PCB/12x6/shell/closedv2.dxf
PCB/12x6/shell/closedv3.dxf
PCB/12x6/shell/open.dxf
PCB/12x6/shell/openV1.dxf
PCB/12x6/shell/openV2.dxf
PCB/12x6/shell/openV3.dxf
PCB/12x6/shell/plate.dxf
PCB/12x6/shell/switch.dxf
PCB/12x6/shell/switchV1.dwg
PCB/18x6/pcb.dxf
PCB/3x10/3D/30/上盖 (1).stl
PCB/3x10/3D/30/底盖.step
PCB/3x10/3D/30/底盖.stl
PCB/3x10/3D/30定位板.dwg
PCB/3x10/3D/30定位板.dxf
PCB/3x10/3D/30定位板v1.dxf
PCB/3x10/3D/stepp/上盖 (1).step
PCB/3x10/3D/加宽一点/30上盖 (1).stl
PCB/3x10/3D/底盖.stl
PCB/3x10/closepcb.dxf
PCB/3x10/pcbv2 - Copy.dxf
PCB/3x10/shell/2013/3x10switchV1.dxf
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

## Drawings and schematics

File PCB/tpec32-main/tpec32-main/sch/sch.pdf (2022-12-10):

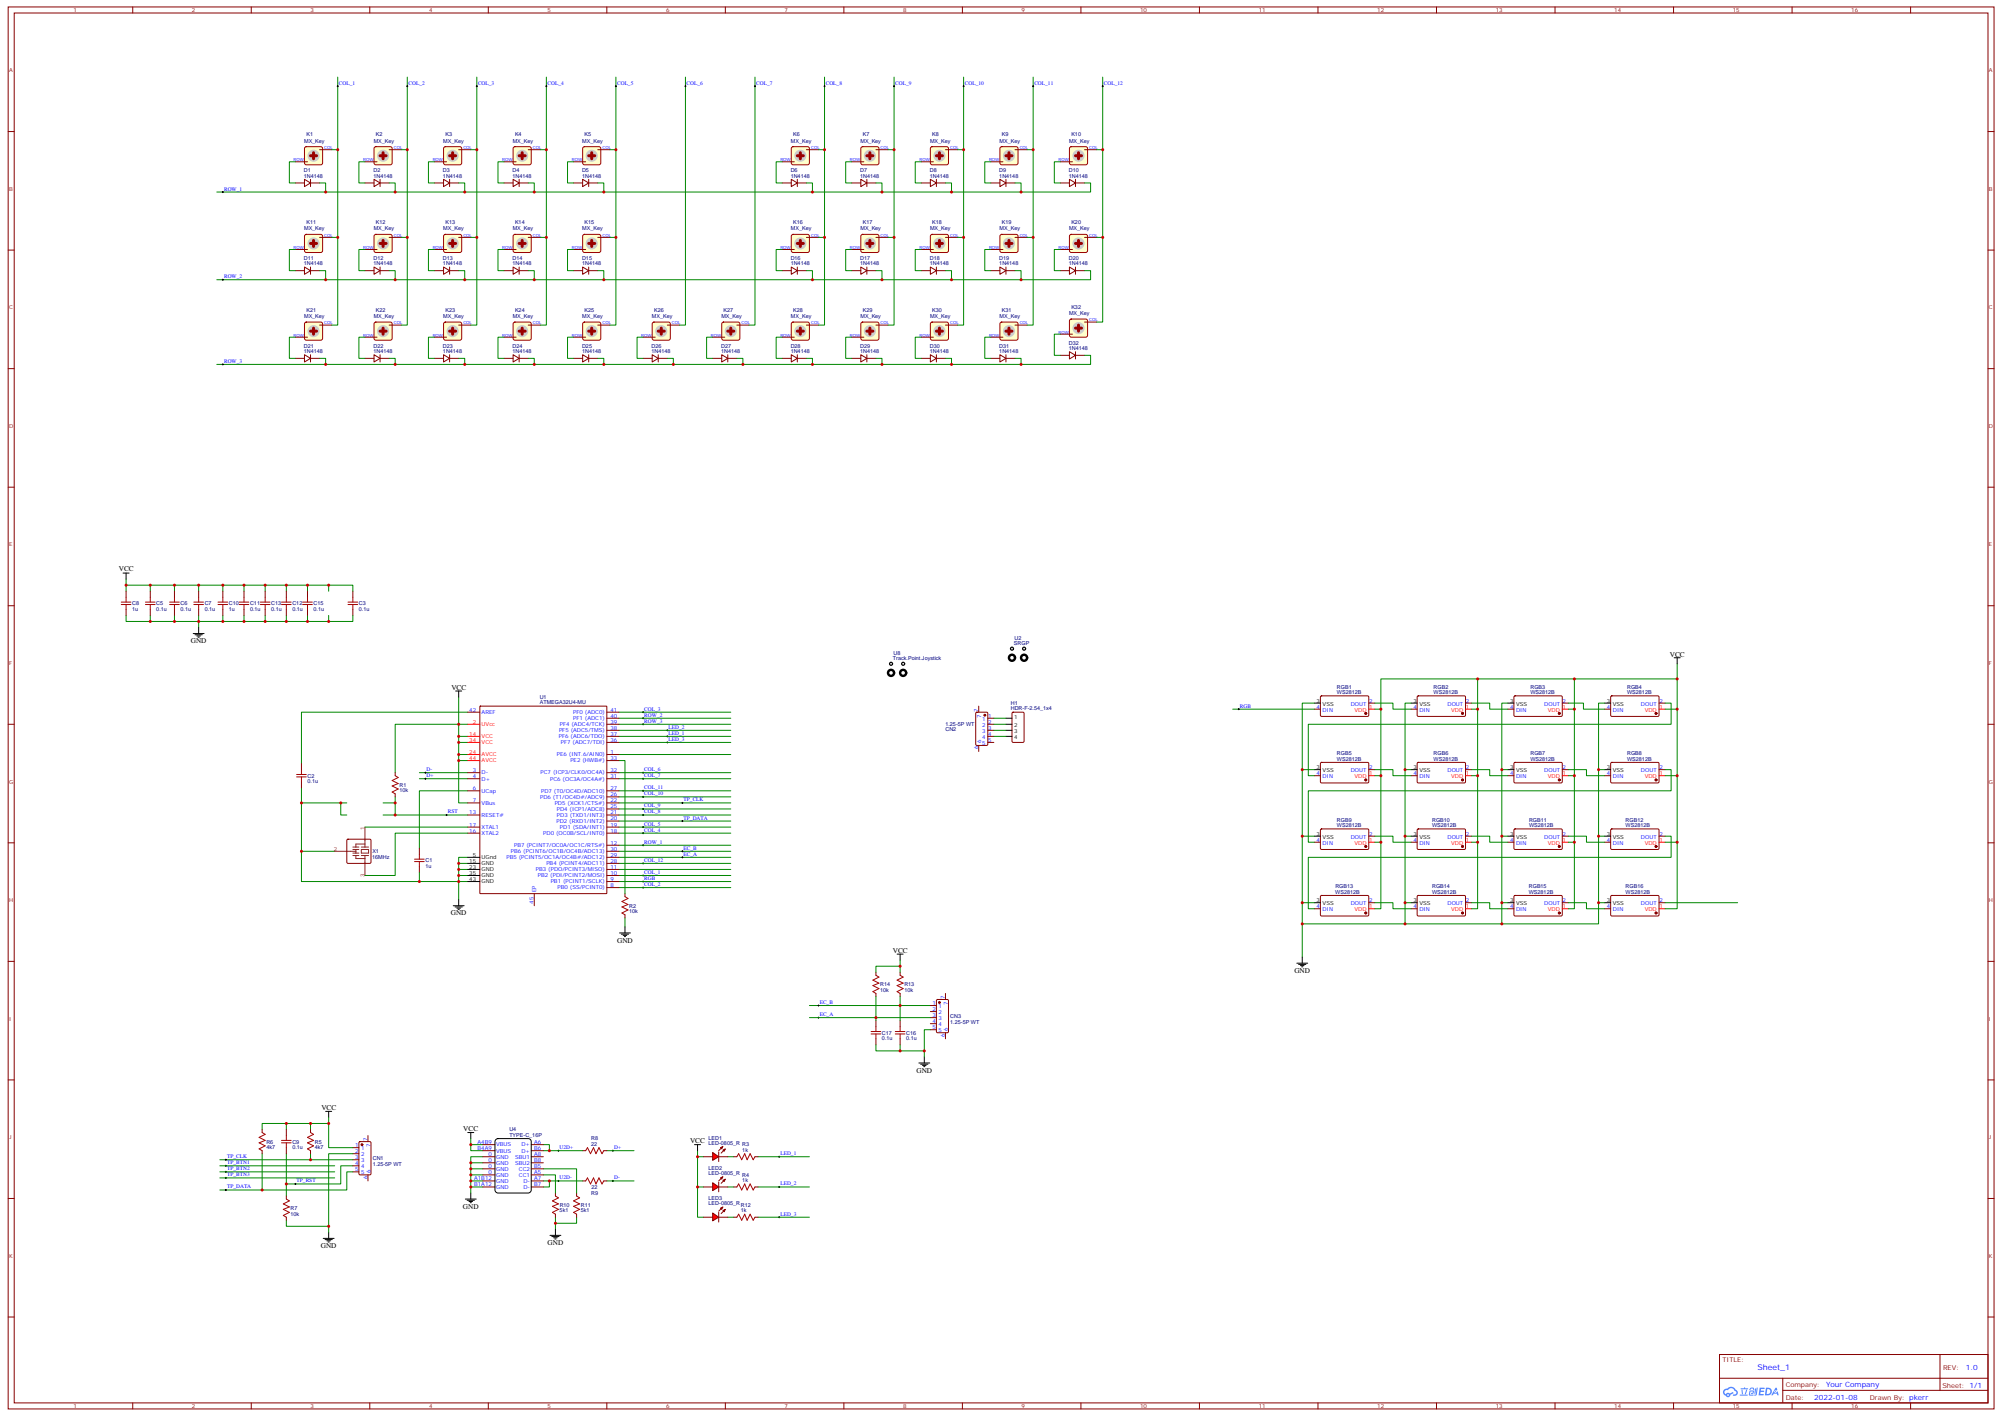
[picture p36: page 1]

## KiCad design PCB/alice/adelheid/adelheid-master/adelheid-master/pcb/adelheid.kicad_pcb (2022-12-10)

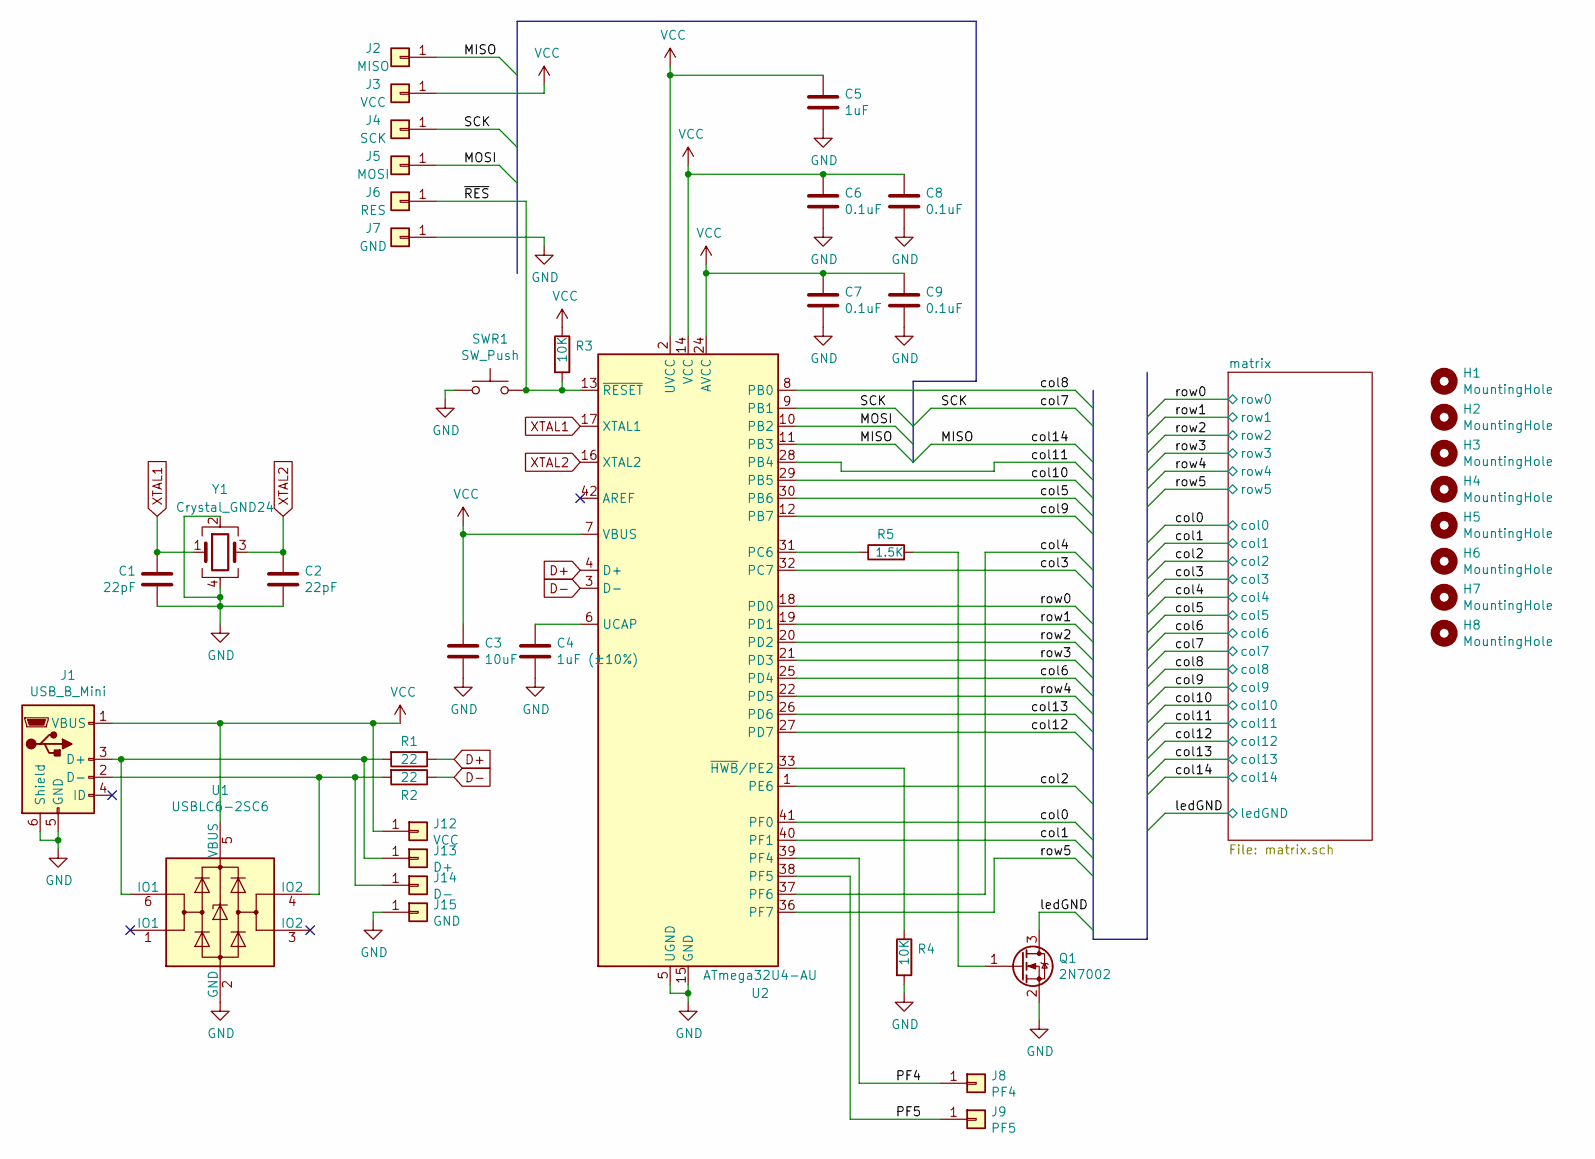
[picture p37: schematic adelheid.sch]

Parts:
C1, C2: 22pF; C_0805_HandSoldering
C3: 10uF; C_0805_HandSoldering
C4: 1uF (±10%); C_0805_HandSoldering
C5: 1uF; C_0805_HandSoldering
C6, C7, C8, C9: 0.1uF; C_0805_HandSoldering
H1, H2, H3, H4, H5, H6, H7, H8: MountingHole; MountingHole_2.2mm_M2_Pad
J1: USB_B_Mini; USB-Mini-B_2leg
J2: MISO; Pin_Header_Straight_1x01_Pitch2.54mm
J3, J12: VCC; Pin_Header_Straight_1x01_Pitch2.54mm
J4: SCK; Pin_Header_Straight_1x01_Pitch2.54mm
J5: MOSI; Pin_Header_Straight_1x01_Pitch2.54mm
J6: RES; Pin_Header_Straight_1x01_Pitch2.54mm
J7, J15: GND; Pin_Header_Straight_1x01_Pitch2.54mm
J8: PF4; Pin_Header_Straight_1x01_Pitch2.54mm
J9: PF5; Pin_Header_Straight_1x01_Pitch2.54mm
J13: D+; Pin_Header_Straight_1x01_Pitch2.54mm
J14: D-; Pin_Header_Straight_1x01_Pitch2.54mm
Q1: 2N7002; SOT-23
R1, R2: 22; R_0805_2012Metric_Pad1.15x1.40mm_HandSolder
R3, R4: 10K; R_0805_2012Metric_Pad1.15x1.40mm_HandSolder
R5: 1.5K; R_0805_2012Metric_Pad1.15x1.40mm_HandSolder
SWR1: SW_Push; SW_SPST_TL3342
U1: USBLC6-2SC6; SOT-23-6_Handsoldering
U2: ATmega32U4-AU; TQFP-44_10x10mm_Pitch0.8mm
Y1: Crystal_GND24; Crystal_SMD_SeikoEpson_FA238-4pin_3.2x2.5mm_HandSoldering

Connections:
/MISO: J2.1, U2.11 (PB3); also elsewhere on the board
/MOSI: J5.1, U2.10 (PB2)
/PF4: J8.1, U2.39 (PF4)
/PF5: J9.1, U2.38 (PF5)
/SCK: J4.1, U2.9 (PB1); also elsewhere on the board
/col0: U2.41 (PF0); also elsewhere on the board
/col1: U2.40 (PF1); also elsewhere on the board
/col2: U2.1 (PE6); also elsewhere on the board
/col3: U2.32 (PC7); also elsewhere on the board
/col4: U2.37 (PF6); also elsewhere on the board
/col5: U2.30 (PB6); also elsewhere on the board
/col6: U2.25 (PD4); also elsewhere on the board
/col8: U2.8 (PB0); also elsewhere on the board
/col9: U2.12 (PB7); also elsewhere on the board
/col10: U2.29 (PB5); also elsewhere on the board
/col11: U2.28 (PB4); also elsewhere on the board
/col12: U2.27 (PD7); also elsewhere on the board
/col13: U2.26 (PD6); also elsewhere on the board
/ledGND: Q1.3 (D); also elsewhere on the board
/row0: U2.18 (PD0); also elsewhere on the board
/row1: U2.19 (PD1); also elsewhere on the board
/row2: U2.20 (PD2); also elsewhere on the board
/row3: U2.21 (PD3); also elsewhere on the board
/row4: U2.22 (PD5); also elsewhere on the board
/row5: U2.36 (PF7); also elsewhere on the board
/~RES~: J6.1, R3.2, SWR1.2, U2.13 (~RESET)
D+: R1.1, U2.4 (D+)
D-: R2.1, U2.3 (D-)
GND: C1.1, C2.2, C3.2, C4.2, C5.2, C6.2, C7.2, C8.2, C9.2, J1.5 (GND), J1.6 (Shield), J7.1, J15.1, Q1.2 (S), R4.2, SWR1.1, U1.2 (GND), U2.5 (UGND), U2.15 (GND), U2.23 (GND), U2.35 (GND), U2.43 (GND), Y1.2, Y1.4
unnamed: C4.1, U2.6 (UCAP)
unnamed: J1.2 (D-), J14.1, R2.2, U1.4 (IO2)
unnamed: J1.3 (D+), J13.1, R1.2, U1.6 (IO1)
unnamed: Q1.1 (G), R5.2
unnamed: R4.1, U2.33 (~HWB~/PE2)
unnamed: R5.1, U2.31 (PC6)
VCC: C3.1, C5.1, C6.1, C7.1, C8.1, C9.1, J1.1 (VBUS), J3.1, J12.1, R3.1, U1.5 (VBUS), U2.2 (UVCC), U2.7 (VBUS), U2.14 (VCC), U2.24 (AVCC), U2.34 (VCC), U2.44 (AVCC); also elsewhere on the board
XTAL1: C1.2, U2.17 (XTAL1), Y1.1
XTAL2: C2.1, U2.16 (XTAL2), Y1.3

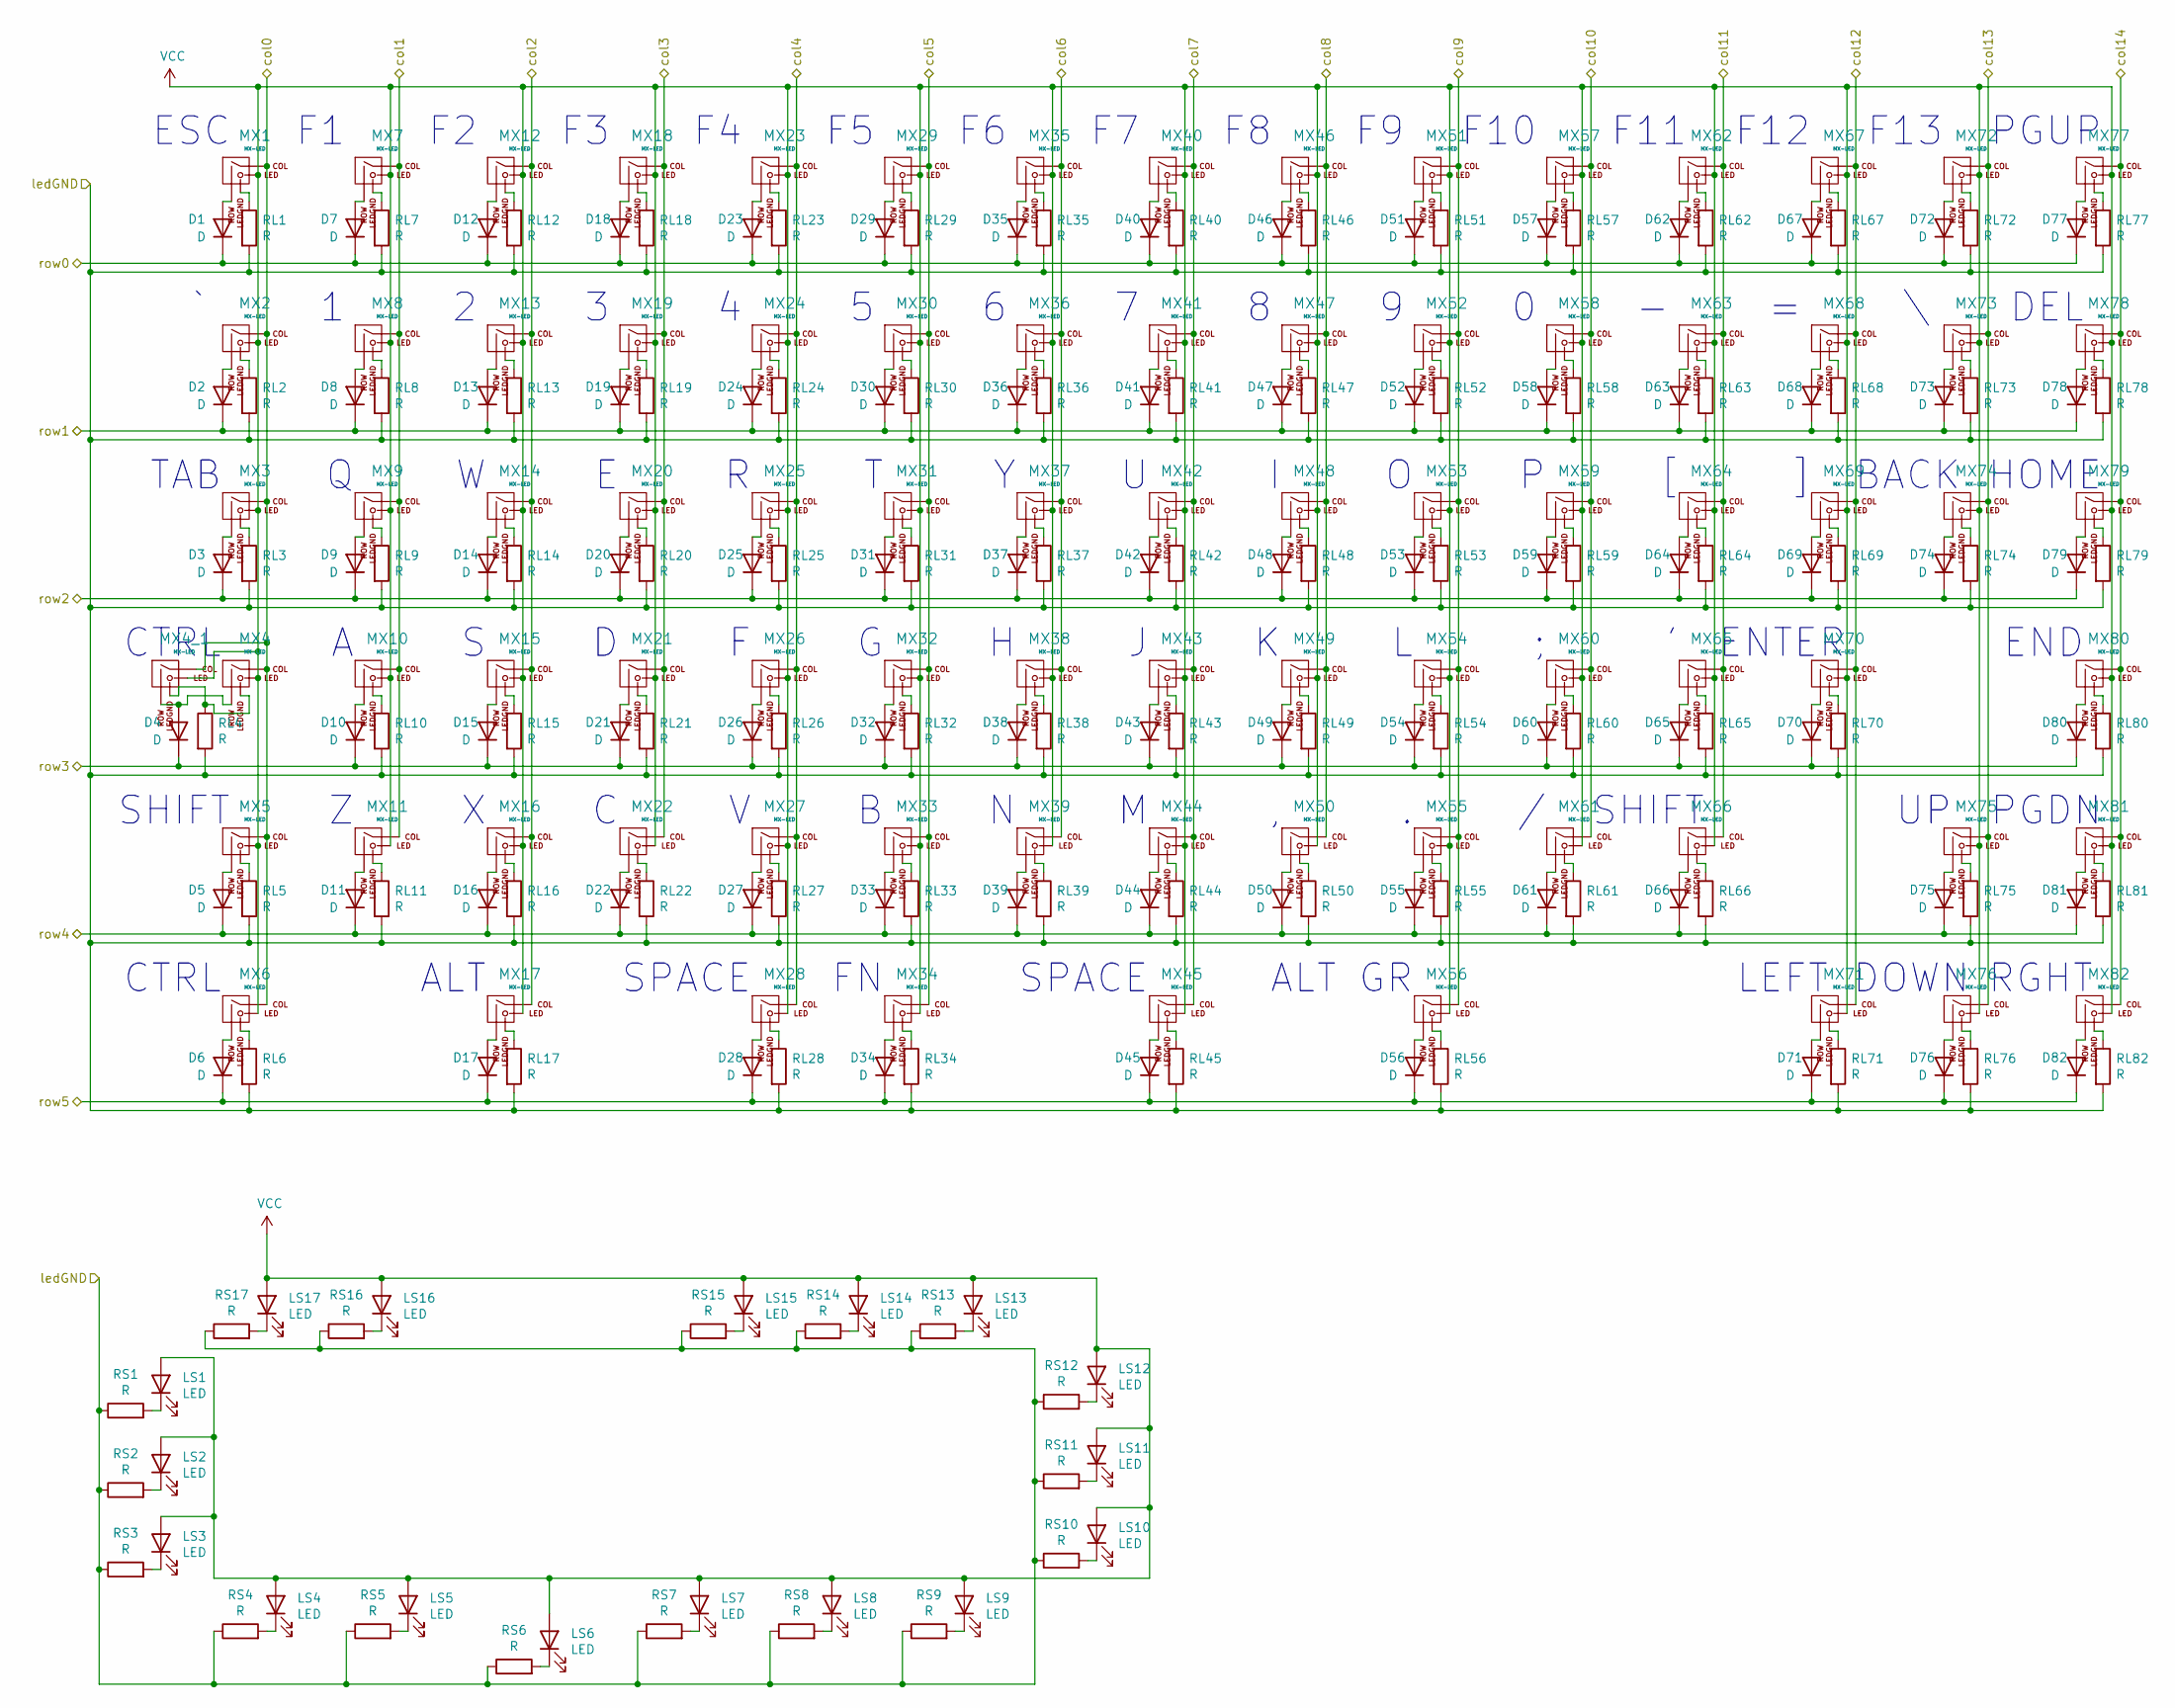
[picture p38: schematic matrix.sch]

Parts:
D1, D2, D3, D4, D5, D6, D7, D8, D9, D10, D11, D12, D13, D14, D15, D16, D17, D18, D19, D20, D21, D22, D23, D24, D25, D26, D27, D28, D29, D30, D31, D32, D33, D34, D35, D36, D37, D38, D39, D40, D41, D42, D43, D44, D45, D46, D47, D48, D49, D50, D51, D52, D53, D54, D55, D56, D57, D58, D59, D60, D61, D62, D63, D64, D65, D66, D67, D68, D69, D70, D71, D72, D73, D74, D75, D76, D77, D78, D79, D80, D81, D82: D; D_SOD-123
LS1, LS2, LS3, LS4, LS5, LS6, LS7, LS8, LS9, LS10, LS11, LS12, LS13, LS14, LS15, LS16, LS17: LED; LED_0805_2012Metric_Pad1.15x1.40mm_HandSolder
MX1, MX2, MX7, MX8, MX9, MX10, MX11, MX12, MX13, MX14, MX15, MX16, MX18, MX19, MX20, MX21, MX22, MX23, MX24, MX25, MX26, MX27, MX29, MX30, MX31, MX32, MX33, MX34, MX35, MX36, MX37, MX38, MX39, MX40, MX41, MX42, MX43, MX44, MX46, MX47, MX48, MX49, MX50, MX51, MX52, MX53, MX54, MX55, MX57, MX58, MX59, MX60, MX61, MX62, MX63, MX64, MX65, MX67, MX68, MX69, MX71, MX72, MX73, MX75, MX76, MX77, MX78, MX79, MX80, MX81, MX82: MX-LED; MXOnly-1U
MX3, MX6, MX17, MX56, MX74: MX-LED; MXOnly-1.5U
MX4, MX66: MX-LED; MXOnly-1.75U
MX4_1: MX-LED; MXOnly-1.75U-FLIPPED
MX5: MX-LED; MXOnly-2.25U
MX28: MX-LED; MXOnly-2U-ReversedStabilizers
MX45: MX-LED; MXOnly-2.75U-ReversedStabilizers
MX70: MX-LED; MXOnly-2.25U-ReversedStabilizers
RL1, RL2, RL3, RL4, RL5, RL6, RL7, RL8, RL9, RL10, RL11, RL12, RL13, RL14, RL15, RL16, RL17, RL18, RL19, RL20, RL21, RL22, RL23, RL24, RL25, RL26, RL27, RL28, RL29, RL30, RL31, RL32, RL33, RL34, RL35, RL36, RL37, RL38, RL39, RL40, RL41, RL42, RL43, RL44, RL45, RL46, RL47, RL48, RL49, RL50, RL51, RL52, RL53, RL54, RL55, RL56, RL57, RL58, RL59, RL60, RL61, RL62, RL63, RL64, RL65, RL66, RL67, RL68, RL69, RL70, RL71, RL72, RL73, RL74, RL75, RL76, RL77, RL78, RL79, RL80, RL81, RL82: R; R_0805_2012Metric_Pad1.15x1.40mm_HandSolder
RS1, RS2, RS3, RS4, RS5, RS6, RS7, RS8, RS9, RS10, RS11, RS12, RS13, RS14, RS15, RS16, RS17: R; R_0805_2012Metric_Pad1.15x1.40mm_HandSolder

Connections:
/MISO: MX77.1 (COL), MX78.1 (COL), MX79.1 (COL), MX80.1 (COL), MX81.1 (COL), MX82.1 (COL); also elsewhere on the board
/SCK: MX40.1 (COL), MX41.1 (COL), MX42.1 (COL), MX43.1 (COL), MX44.1 (COL), MX45.1 (COL); also elsewhere on the board
/col0: MX1.1 (COL), MX2.1 (COL), MX3.1 (COL), MX4.1 (COL), MX4_1.1 (COL), MX5.1 (COL), MX6.1 (COL); also elsewhere on the board
/col1: MX7.1 (COL), MX8.1 (COL), MX9.1 (COL), MX10.1 (COL), MX11.1 (COL); also elsewhere on the board
/col2: MX12.1 (COL), MX13.1 (COL), MX14.1 (COL), MX15.1 (COL), MX16.1 (COL), MX17.1 (COL); also elsewhere on the board
/col3: MX18.1 (COL), MX19.1 (COL), MX20.1 (COL), MX21.1 (COL), MX22.1 (COL); also elsewhere on the board
/col4: MX23.1 (COL), MX24.1 (COL), MX25.1 (COL), MX26.1 (COL), MX27.1 (COL), MX28.1 (COL); also elsewhere on the board
/col5: MX29.1 (COL), MX30.1 (COL), MX31.1 (COL), MX32.1 (COL), MX33.1 (COL), MX34.1 (COL); also elsewhere on the board
/col6: MX35.1 (COL), MX36.1 (COL), MX37.1 (COL), MX38.1 (COL), MX39.1 (COL); also elsewhere on the board
/col8: MX46.1 (COL), MX47.1 (COL), MX48.1 (COL), MX49.1 (COL), MX50.1 (COL); also elsewhere on the board
/col9: MX51.1 (COL), MX52.1 (COL), MX53.1 (COL), MX54.1 (COL), MX55.1 (COL), MX56.1 (COL); also elsewhere on the board
/col10: MX57.1 (COL), MX58.1 (COL), MX59.1 (COL), MX60.1 (COL), MX61.1 (COL); also elsewhere on the board
/col11: MX62.1 (COL), MX63.1 (COL), MX64.1 (COL), MX65.1 (COL), MX66.1 (COL); also elsewhere on the board
/col12: MX67.1 (COL), MX68.1 (COL), MX69.1 (COL), MX70.1 (COL), MX71.1 (COL); also elsewhere on the board
/col13: MX72.1 (COL), MX73.1 (COL), MX74.1 (COL), MX75.1 (COL), MX76.1 (COL); also elsewhere on the board
/ledGND: RL1.2, RL2.2, RL3.2, RL4.2, RL5.2, RL6.2, RL7.2, RL8.2, RL9.2, RL10.2, RL11.2, RL12.2, RL13.2, RL14.2, RL15.2, RL16.2, RL17.2, RL18.2, RL19.2, RL20.2, RL21.2, RL22.2, RL23.2, RL24.2, RL25.2, RL26.2, RL27.2, RL28.2, RL29.2, RL30.2, RL31.2, RL32.2, RL33.2, RL34.2, RL35.2, RL36.2, RL37.2, RL38.2, RL39.2, RL40.2, RL41.2, RL42.2, RL43.2, RL44.2, RL45.2, RL46.2, RL47.2, RL48.2, RL49.2, RL50.2, RL51.2, RL52.2, RL53.2, RL54.2, RL55.2, RL56.2, RL57.2, RL58.2, RL59.2, RL60.2, RL61.2, RL62.2, RL63.2, RL64.2, RL65.2, RL66.2, RL67.2, RL68.2, RL69.2, RL70.2, RL71.2, RL72.2, RL73.2, RL74.2, RL75.2, RL76.2, RL77.2, RL78.2, RL79.2, RL80.2, RL81.2, RL82.2, RS1.1, RS2.1, RS3.1, RS4.1, RS5.1, RS6.1, RS7.1, RS8.1, RS9.1, RS10.1, RS11.1, RS12.1, RS13.1, RS14.1, RS15.1, RS16.1, RS17.1; also elsewhere on the board
/row0: D1.1 (K), D7.1 (K), D12.1 (K), D18.1 (K), D23.1 (K), D29.1 (K), D35.1 (K), D40.1 (K), D46.1 (K), D51.1 (K), D57.1 (K), D62.1 (K), D67.1 (K), D72.1 (K), D77.1 (K); also elsewhere on the board
/row1: D2.1 (K), D8.1 (K), D13.1 (K), D19.1 (K), D24.1 (K), D30.1 (K), D36.1 (K), D41.1 (K), D47.1 (K), D52.1 (K), D58.1 (K), D63.1 (K), D68.1 (K), D73.1 (K), D78.1 (K); also elsewhere on the board
/row2: D3.1 (K), D9.1 (K), D14.1 (K), D20.1 (K), D25.1 (K), D31.1 (K), D37.1 (K), D42.1 (K), D48.1 (K), D53.1 (K), D59.1 (K), D64.1 (K), D69.1 (K), D74.1 (K), D79.1 (K); also elsewhere on the board
/row3: D4.1 (K), D10.1 (K), D15.1 (K), D21.1 (K), D26.1 (K), D32.1 (K), D38.1 (K), D43.1 (K), D49.1 (K), D54.1 (K), D60.1 (K), D65.1 (K), D70.1 (K), D80.1 (K); also elsewhere on the board
/row4: D5.1 (K), D11.1 (K), D16.1 (K), D22.1 (K), D27.1 (K), D33.1 (K), D39.1 (K), D44.1 (K), D50.1 (K), D55.1 (K), D61.1 (K), D66.1 (K), D75.1 (K), D81.1 (K); also elsewhere on the board
/row5: D6.1 (K), D17.1 (K), D28.1 (K), D34.1 (K), D45.1 (K), D56.1 (K), D71.1 (K), D76.1 (K), D82.1 (K); also elsewhere on the board
unnamed: D1.2 (A), MX1.2 (ROW)
unnamed: D2.2 (A), MX2.2 (ROW)
unnamed: D3.2 (A), MX3.2 (ROW)
unnamed: D4.2 (A), MX4.2 (ROW), MX4_1.2 (ROW)
unnamed: D5.2 (A), MX5.2 (ROW)
unnamed: D6.2 (A), MX6.2 (ROW)
unnamed: D7.2 (A), MX7.2 (ROW)
unnamed: D8.2 (A), MX8.2 (ROW)
unnamed: D9.2 (A), MX9.2 (ROW)
unnamed: D10.2 (A), MX10.2 (ROW)
unnamed: D11.2 (A), MX11.2 (ROW)
unnamed: D12.2 (A), MX12.2 (ROW)
unnamed: D13.2 (A), MX13.2 (ROW)
unnamed: D14.2 (A), MX14.2 (ROW)
unnamed: D15.2 (A), MX15.2 (ROW)
unnamed: D16.2 (A), MX16.2 (ROW)
unnamed: D17.2 (A), MX17.2 (ROW)
unnamed: D18.2 (A), MX18.2 (ROW)
unnamed: D19.2 (A), MX19.2 (ROW)
unnamed: D20.2 (A), MX20.2 (ROW)
unnamed: D21.2 (A), MX21.2 (ROW)
unnamed: D22.2 (A), MX22.2 (ROW)
unnamed: D23.2 (A), MX23.2 (ROW)
unnamed: D24.2 (A), MX24.2 (ROW)
unnamed: D25.2 (A), MX25.2 (ROW)
unnamed: D26.2 (A), MX26.2 (ROW)
unnamed: D27.2 (A), MX27.2 (ROW)
unnamed: D28.2 (A), MX28.2 (ROW)
unnamed: D29.2 (A), MX29.2 (ROW)
unnamed: D30.2 (A), MX30.2 (ROW)
unnamed: D31.2 (A), MX31.2 (ROW)
unnamed: D32.2 (A), MX32.2 (ROW)
unnamed: D33.2 (A), MX33.2 (ROW)
unnamed: D34.2 (A), MX34.2 (ROW)
unnamed: D35.2 (A), MX35.2 (ROW)
unnamed: D36.2 (A), MX36.2 (ROW)
unnamed: D37.2 (A), MX37.2 (ROW)
unnamed: D38.2 (A), MX38.2 (ROW)
unnamed: D39.2 (A), MX39.2 (ROW)
unnamed: D40.2 (A), MX40.2 (ROW)
unnamed: D41.2 (A), MX41.2 (ROW)
unnamed: D42.2 (A), MX42.2 (ROW)
unnamed: D43.2 (A), MX43.2 (ROW)
unnamed: D44.2 (A), MX44.2 (ROW)
unnamed: D45.2 (A), MX45.2 (ROW)
unnamed: D46.2 (A), MX46.2 (ROW)
unnamed: D47.2 (A), MX47.2 (ROW)
unnamed: D48.2 (A), MX48.2 (ROW)
unnamed: D49.2 (A), MX49.2 (ROW)
unnamed: D50.2 (A), MX50.2 (ROW)
unnamed: D51.2 (A), MX51.2 (ROW)
unnamed: D52.2 (A), MX52.2 (ROW)
unnamed: D53.2 (A), MX53.2 (ROW)
unnamed: D54.2 (A), MX54.2 (ROW)
unnamed: D55.2 (A), MX55.2 (ROW)
unnamed: D56.2 (A), MX56.2 (ROW)
unnamed: D57.2 (A), MX57.2 (ROW)
unnamed: D58.2 (A), MX58.2 (ROW)
unnamed: D59.2 (A), MX59.2 (ROW)
unnamed: D60.2 (A), MX60.2 (ROW)
unnamed: D61.2 (A), MX61.2 (ROW)
unnamed: D62.2 (A), MX62.2 (ROW)
unnamed: D63.2 (A), MX63.2 (ROW)
unnamed: D64.2 (A), MX64.2 (ROW)
unnamed: D65.2 (A), MX65.2 (ROW)
unnamed: D66.2 (A), MX66.2 (ROW)
unnamed: D67.2 (A), MX67.2 (ROW)
unnamed: D68.2 (A), MX68.2 (ROW)
unnamed: D69.2 (A), MX69.2 (ROW)
unnamed: D70.2 (A), MX70.2 (ROW)
unnamed: D71.2 (A), MX71.2 (ROW)
unnamed: D72.2 (A), MX72.2 (ROW)
unnamed: D73.2 (A), MX73.2 (ROW)
unnamed: D74.2 (A), MX74.2 (ROW)
unnamed: D75.2 (A), MX75.2 (ROW)
unnamed: D76.2 (A), MX76.2 (ROW)
unnamed: D77.2 (A), MX77.2 (ROW)
unnamed: D78.2 (A), MX78.2 (ROW)
unnamed: D79.2 (A), MX79.2 (ROW)
unnamed: D80.2 (A), MX80.2 (ROW)
unnamed: D81.2 (A), MX81.2 (ROW)
unnamed: D82.2 (A), MX82.2 (ROW)
unnamed: LS1.1 (K), RS1.2
unnamed: LS2.1 (K), RS2.2
unnamed: LS3.1 (K), RS3.2
unnamed: LS4.1 (K), RS4.2
unnamed: LS5.1 (K), RS5.2
unnamed: LS6.1 (K), RS6.2
unnamed: LS7.1 (K), RS7.2
unnamed: LS8.1 (K), RS8.2
unnamed: LS9.1 (K), RS9.2
unnamed: LS10.1 (K), RS10.2
unnamed: LS11.1 (K), RS11.2
unnamed: LS12.1 (K), RS12.2
unnamed: LS13.1 (K), RS13.2
unnamed: LS14.1 (K), RS14.2
unnamed: LS15.1 (K), RS15.2
unnamed: LS16.1 (K), RS16.2
unnamed: LS17.1 (K), RS17.2
unnamed: MX1.4 (LEDGND), RL1.1
unnamed: MX2.4 (LEDGND), RL2.1
unnamed: MX3.4 (LEDGND), RL3.1
unnamed: MX4.4 (LEDGND), MX4_1.4 (LEDGND), RL4.1
unnamed: MX5.4 (LEDGND), RL5.1
unnamed: MX6.4 (LEDGND), RL6.1
unnamed: MX7.4 (LEDGND), RL7.1
unnamed: MX8.4 (LEDGND), RL8.1
unnamed: MX9.4 (LEDGND), RL9.1
unnamed: MX10.4 (LEDGND), RL10.1
unnamed: MX11.4 (LEDGND), RL11.1
unnamed: MX12.4 (LEDGND), RL12.1
unnamed: MX13.4 (LEDGND), RL13.1
unnamed: MX14.4 (LEDGND), RL14.1
unnamed: MX15.4 (LEDGND), RL15.1
unnamed: MX16.4 (LEDGND), RL16.1
unnamed: MX17.4 (LEDGND), RL17.1
unnamed: MX18.4 (LEDGND), RL18.1
unnamed: MX19.4 (LEDGND), RL19.1
unnamed: MX20.4 (LEDGND), RL20.1
unnamed: MX21.4 (LEDGND), RL21.1
unnamed: MX22.4 (LEDGND), RL22.1
unnamed: MX23.4 (LEDGND), RL23.1
unnamed: MX24.4 (LEDGND), RL24.1
unnamed: MX25.4 (LEDGND), RL25.1
unnamed: MX26.4 (LEDGND), RL26.1
unnamed: MX27.4 (LEDGND), RL27.1
unnamed: MX28.4 (LEDGND), RL28.1
unnamed: MX29.4 (LEDGND), RL29.1
unnamed: MX30.4 (LEDGND), RL30.1
unnamed: MX31.4 (LEDGND), RL31.1
unnamed: MX32.4 (LEDGND), RL32.1
unnamed: MX33.4 (LEDGND), RL33.1
unnamed: MX34.4 (LEDGND), RL34.1
unnamed: MX35.4 (LEDGND), RL35.1
unnamed: MX36.4 (LEDGND), RL36.1
unnamed: MX37.4 (LEDGND), RL37.1
unnamed: MX38.4 (LEDGND), RL38.1
unnamed: MX39.4 (LEDGND), RL39.1
unnamed: MX40.4 (LEDGND), RL40.1
unnamed: MX41.4 (LEDGND), RL41.1
unnamed: MX42.4 (LEDGND), RL42.1
unnamed: MX43.4 (LEDGND), RL43.1
unnamed: MX44.4 (LEDGND), RL44.1
unnamed: MX45.4 (LEDGND), RL45.1
unnamed: MX46.4 (LEDGND), RL46.1
unnamed: MX47.4 (LEDGND), RL47.1
unnamed: MX48.4 (LEDGND), RL48.1
unnamed: MX49.4 (LEDGND), RL49.1
unnamed: MX50.4 (LEDGND), RL50.1
unnamed: MX51.4 (LEDGND), RL51.1
unnamed: MX52.4 (LEDGND), RL52.1
unnamed: MX53.4 (LEDGND), RL53.1
unnamed: MX54.4 (LEDGND), RL54.1
unnamed: MX55.4 (LEDGND), RL55.1
unnamed: MX56.4 (LEDGND), RL56.1
unnamed: MX57.4 (LEDGND), RL57.1
unnamed: MX58.4 (LEDGND), RL58.1
unnamed: MX59.4 (LEDGND), RL59.1
unnamed: MX60.4 (LEDGND), RL60.1
unnamed: MX61.4 (LEDGND), RL61.1
unnamed: MX62.4 (LEDGND), RL62.1
unnamed: MX63.4 (LEDGND), RL63.1
unnamed: MX64.4 (LEDGND), RL64.1
unnamed: MX65.4 (LEDGND), RL65.1
unnamed: MX66.4 (LEDGND), RL66.1
unnamed: MX67.4 (LEDGND), RL67.1
unnamed: MX68.4 (LEDGND), RL68.1
unnamed: MX69.4 (LEDGND), RL69.1
unnamed: MX70.4 (LEDGND), RL70.1
unnamed: MX71.4 (LEDGND), RL71.1
unnamed: MX72.4 (LEDGND), RL72.1
unnamed: MX73.4 (LEDGND), RL73.1
unnamed: MX74.4 (LEDGND), RL74.1
unnamed: MX75.4 (LEDGND), RL75.1
unnamed: MX76.4 (LEDGND), RL76.1
unnamed: MX77.4 (LEDGND), RL77.1
unnamed: MX78.4 (LEDGND), RL78.1
unnamed: MX79.4 (LEDGND), RL79.1
unnamed: MX80.4 (LEDGND), RL80.1
unnamed: MX81.4 (LEDGND), RL81.1
unnamed: MX82.4 (LEDGND), RL82.1
VCC: LS1.2 (A), LS2.2 (A), LS3.2 (A), LS4.2 (A), LS5.2 (A), LS6.2 (A), LS7.2 (A), LS8.2 (A), LS9.2 (A), LS10.2 (A), LS11.2 (A), LS12.2 (A), LS13.2 (A), LS14.2 (A), LS15.2 (A), LS16.2 (A), LS17.2 (A), MX1.3 (LED), MX2.3 (LED), MX3.3 (LED), MX4.3 (LED), MX4_1.3 (LED), MX5.3 (LED), MX6.3 (LED), MX7.3 (LED), MX8.3 (LED), MX9.3 (LED), MX10.3 (LED), MX11.3 (LED), MX12.3 (LED), MX13.3 (LED), MX14.3 (LED), MX15.3 (LED), MX16.3 (LED), MX17.3 (LED), MX18.3 (LED), MX19.3 (LED), MX20.3 (LED), MX21.3 (LED), MX22.3 (LED), MX23.3 (LED), MX24.3 (LED), MX25.3 (LED), MX26.3 (LED), MX27.3 (LED), MX28.3 (LED), MX29.3 (LED), MX30.3 (LED), MX31.3 (LED), MX32.3 (LED), MX33.3 (LED), MX34.3 (LED), MX35.3 (LED), MX36.3 (LED), MX37.3 (LED), MX38.3 (LED), MX39.3 (LED), MX40.3 (LED), MX41.3 (LED), MX42.3 (LED), MX43.3 (LED), MX44.3 (LED), MX45.3 (LED), MX46.3 (LED), MX47.3 (LED), MX48.3 (LED), MX49.3 (LED), MX50.3 (LED), MX51.3 (LED), MX52.3 (LED), MX53.3 (LED), MX54.3 (LED), MX55.3 (LED), MX56.3 (LED), MX57.3 (LED), MX58.3 (LED), MX59.3 (LED), MX60.3 (LED), MX61.3 (LED), MX62.3 (LED), MX63.3 (LED), MX64.3 (LED), MX65.3 (LED), MX66.3 (LED), MX67.3 (LED), MX68.3 (LED), MX69.3 (LED), MX70.3 (LED), MX71.3 (LED), MX72.3 (LED), MX73.3 (LED), MX74.3 (LED), MX75.3 (LED), MX76.3 (LED), MX77.3 (LED), MX78.3 (LED), MX79.3 (LED), MX80.3 (LED), MX81.3 (LED), MX82.3 (LED); also elsewhere on the board

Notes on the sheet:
ESC
F10
F11
F12
F13
PGUP
DEL
HOME
END
PGDN
RGHT
DOWN
LEFT
TAB
BACK
CTRL
ENTER
SHIFT
ALT
SPACE
ALT GR

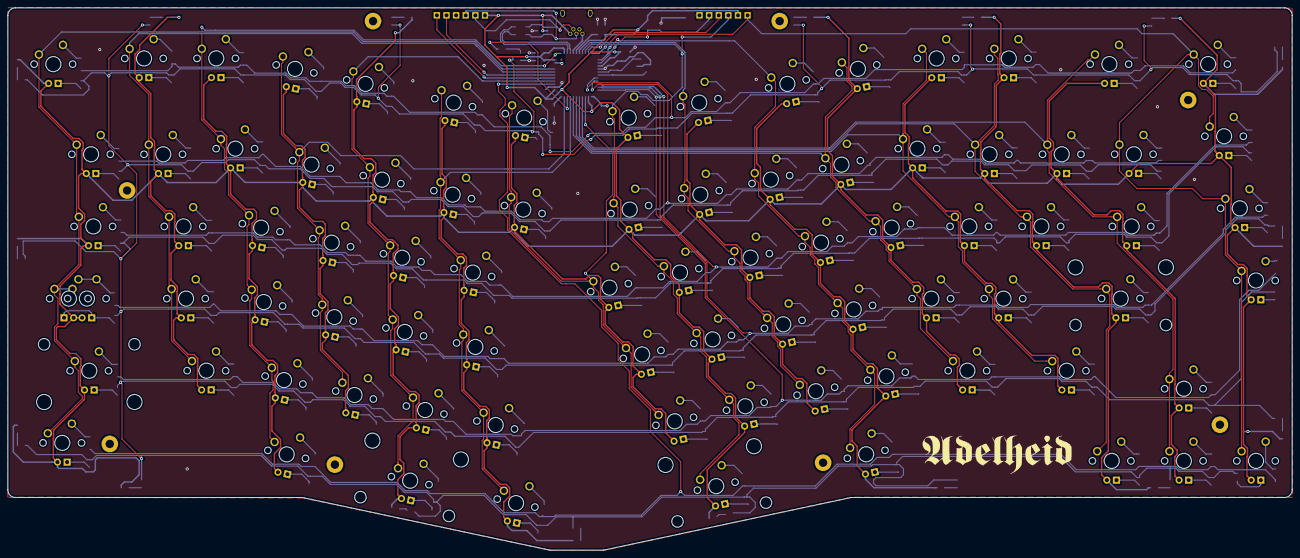
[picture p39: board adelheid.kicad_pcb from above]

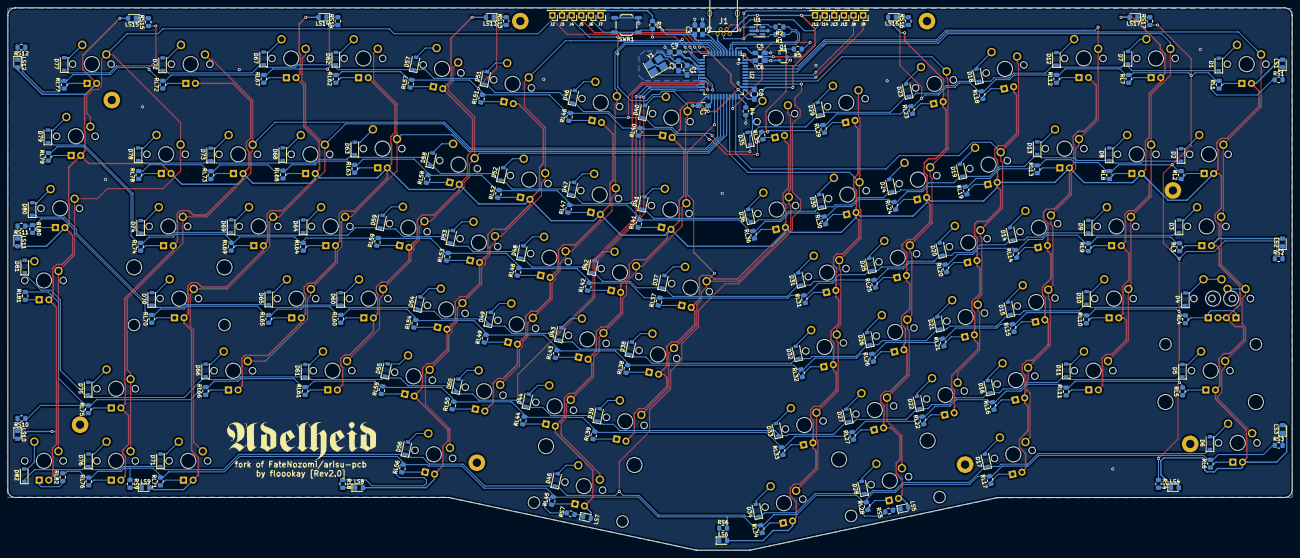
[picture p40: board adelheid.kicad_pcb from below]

Board: 2 copper layers, 339.1 x 143.2 mm, 323 parts (231 on the bottom side), 219 nets.

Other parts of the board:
 G2: LOGO; adelheid-logo
G1: LOGO; adelheid-logo

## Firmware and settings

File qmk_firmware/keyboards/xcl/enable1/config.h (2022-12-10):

#ifndef CONFIG_H
#define CONFIG_H

#include "config_common.h"

/* Device */
#define VENDOR_ID       0xDE32
#define PRODUCT_ID      0x7315
#define DEVICE_VER      0x0002
#define MANUFACTURER    Leo Deng
#define PRODUCT         enaBLE
#define DESCRIPTION     Bluetooth LE 4.2

/* Command */
#define IS_COMMAND() ( keyboard_report->mods == (MOD_BIT(KC_LSHIFT) | MOD_BIT(KC_RSHIFT)) )

/* Matrix */
#define MATRIX_ROWS 2
#define MATRIX_COLS 3
#define MATRIX_ROW_PINS { D3, D2 }
#define MATRIX_COL_PINS { F5, F6, F7 }
#define DIODE_DIRECTION COL2ROW // COL2ROW or ROW2COL

#define DEBOUNCE 5
#define TAP_CODE_DELAY 10
#define PREVENT_STUCK_MODIFIERS

/* BLE */
#define AdafruitBleResetPin D4
#define AdafruitBleCSPin B4
#define AdafruitBleIRQPin E6
// #define BATTERY_LEVEL_PIN B6


/* PS/2 Mouse */
#ifdef PS2_USE_USART
#define PS2_CLOCK_PORT  PORTD
#define PS2_CLOCK_PIN   PIND
#define PS2_CLOCK_DDR   DDRD
#define PS2_CLOCK_BIT   5
#define PS2_DATA_PORT   PORTD
#define PS2_DATA_PIN    PIND
#define PS2_DATA_DDR    DDRD
#define PS2_DATA_BIT    2

/* synchronous, odd parity, 1-bit stop, 8-bit data, sample at falling edge */
/* set DDR of CLOCK as input to be slave */
#define PS2_USART_INIT() do {   \
  PS2_CLOCK_DDR &= ~(1<<PS2_CLOCK_BIT);   \
  PS2_DATA_DDR &= ~(1<<PS2_DATA_BIT);     \
  UCSR1C = ((1 << UMSEL10) |  \
            (3 << UPM10)   |  \
            (0 << USBS1)   |  \
            (3 << UCSZ10)  |  \
            (0 << UCPOL1));   \
  UCSR1A = 0;                 \
  UBRR1H = 0;                 \
  UBRR1L = 0;                 \
} while (0)
#define PS2_USART_RX_INT_ON() do {  \
  UCSR1B = ((1 << RXCIE1) |       \
            (1 << RXEN1));        \
} while (0)
#define PS2_USART_RX_POLL_ON() do { \
  UCSR1B = (1 << RXEN1);          \
} while (0)
#define PS2_USART_OFF() do {    \
  UCSR1C = 0;                 \
  UCSR1B &= ~((1 << RXEN1) |  \
              (1 << TXEN1));  \
} while (0)
#define PS2_USART_RX_READY      (UCSR1A & (1<<RXC1))
#define PS2_USART_RX_DATA       UDR1
#define PS2_USART_ERROR         (UCSR1A & ((1<<FE1) | (1<<DOR1) | (1<<UPE1)))
#define PS2_USART_RX_VECT       USART1_RX_vect

#define PS2_MOUSE_SCROLL_BTN_MASK (1<<PS2_MOUSE_BTN_MIDDLE)
#define PS2_MOUSE_SCROLL_BTN_SEND 300
#define PS2_MOUSE_ROTATE 180
// #define PS2_MOUSE_X_MULTIPLIER 1
// #define PS2_MOUSE_Y_MULTIPLIER 1
#define PS2_MOUSE_V_MULTIPLIER 0.1
#endif

/* RGB Matrix */
#ifdef RGB_MATRIX_ENABLE
// #define DRIVER_ADDR_1 0b1110100
// #define DRIVER_COUNT 1
#define RGB_DI_PIN F4
#define DRIVER_LED_TOTAL 3
#define RGBLIGHT_ANIMATIONS
#define RGB_MATRIX_KEYPRESSES
#define RGB_DISABLE_WHEN_USB_SUSPENDED true
#define RGB_MATRIX_MAXIMUM_BRIGHTNESS 150
#define RGB_MATRIX_TYPING_HEATMAP_DECREASE_DELAY_MS 50
#define RGB_MATRIX_FRAMEBUFFER_EFFECTS
#define RGB_MATRIX_HUE_STEP 8
#define RGB_MATRIX_SAT_STEP 8
#define RGB_MATRIX_VAL_STEP 8
#define RGB_MATRIX_SPD_STEP 10

// #define RGBLED_NUM 3
// #define RGBLIGHT_ANIMATIONS
// #define RGBLIGHT_HUE_STEP 8
// #define RGBLIGHT_SAT_STEP 8
// #define RGBLIGHT_VAL_STEP 8
// #define RGBLIGHT_LIMIT_VAL 155

// #define RGB_MATRIX_KEYPRESSES
// #define RGB_MATRIX_MAXIMUM_BRIGHTNESS 100
// #define RGB_MATRIX_STARTUP_MODE RGB_MATRIX_CYCLE_LEFT_RIGHT
// #define RGB_MATRIX_STARTUP_HUE 0
// #define RGB_MATRIX_STARTUP_SAT 255
// #define RGB_MATRIX_STARTUP_VAL RGB_MATRIX_MAXIMUM_BRIGHTNESS
// #define RGB_MATRIX_STARTUP_SPD 127
// #define RGB_MATRIX_DISABLE_KEYCODES
// #define RGB_DISABLE_TIMEOUT 0
// #define RGB_DISABLE_AFTER_TIMEOUT 0
// #define RGB_DISABLE_WHEN_USB_SUSPENDED true
// #define RGB_MATRIX_LED_PROCESS_LIMIT (DRIVER_LED_TOTAL + 4) / 5
// #define RGB_MATRIX_LED_FLUSH_LIMIT 16
#endif

#endif

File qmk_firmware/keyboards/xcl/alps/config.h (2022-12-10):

#ifndef CONFIG_H
#define CONFIG_H

#include "config_common.h"

/* Device */
#define VENDOR_ID       0xDE29
#define PRODUCT_ID      0x7311
#define DEVICE_VER      0x0001
#define MANUFACTURER    Leo Deng
#define PRODUCT         Alps
#define DESCRIPTION     RKJXT1F42001

/* Command */
#define IS_COMMAND() ( keyboard_report->mods == (MOD_BIT(KC_LSHIFT) | MOD_BIT(KC_RSHIFT)) )

/* Matrix */
#define MATRIX_ROWS 1
#define MATRIX_COLS 5
#define MATRIX_ROW_PINS { B5 }
#define MATRIX_COL_PINS { D1, D0, D4, C6, D7 }
#define DIODE_DIRECTION COL2ROW // COL2ROW or ROW2COL

#define DEBOUNCE 5
#define TAP_CODE_DELAY 10
#define PREVENT_STUCK_MODIFIERS

/* Encoder */
#define ENCODERS_PAD_A { D2 }
#define ENCODERS_PAD_B { D3 }

/* WS2812 RGB */
#define RGB_DI_PIN F4
#define RGBLED_NUM 3
#define RGBLIGHT_ANIMATIONS
#define RGBLIGHT_HUE_STEP 8
#define RGBLIGHT_SAT_STEP 8
#define RGBLIGHT_VAL_STEP 8

#endif

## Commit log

2022-12-10 All
    All
    [01 Case bottom.dxf, 02 Case gasket no usb.dxf, 03 Case gasket.dxf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]
2022-12-10 大概的流程
